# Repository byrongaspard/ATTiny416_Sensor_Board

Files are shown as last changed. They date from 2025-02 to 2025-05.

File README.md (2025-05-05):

# ATTiny416 Dev Board

This project is my first attempt at embedded hardware/software design where I layout/route a custom PCB. In my professional career, I have done schematic capture, integrated Arduino and Raspberry Pi like development boards into custom solutions, and developed embedded software, but this will be my first time laying out a custom circuit card.

There were no real requirements for this design as the primary objective was to learn how to layout a PCB using KiCad. However, to make the design process a little more interesting, I decided I wanted the board to have the following features:

- USB to UART communication to/from the microcontroller
- 3.3V microcontroller (instead of 5V)
- Includes SPI flash for recording data
- Accepts/regulates power from multiple inputs:
  - 5 V from USB
  - 30V from an external power source

The following image is the of the final board. The sections that follow will describe the more interesting portions of the design.

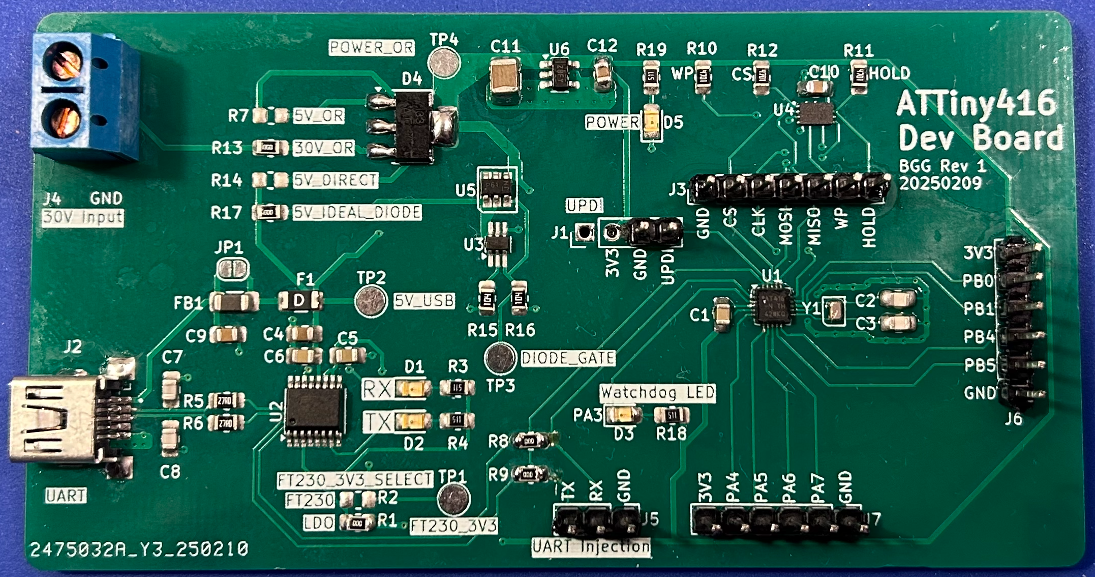
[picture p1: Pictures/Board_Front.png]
Board Front


## Relevant Repository Links

- [KiCad Schematics](KiCad/): Contains the KiCad schematics for the electrical design
  - [Schematic Plots](KiCad/Plots/): Contains the PDF schematics plots for the electrical design
- [SPICE files](SPICE): Contains the LTSpice models used in the design
- [Code](Code): Contains the test code developed for the design

## Hardware Design

The first step in this hardware design was selecting a microcontroller. The ATTiny416 was chosen because of its interesting form factor. It comes in a very small (3x3mm) VQFN package while still providing a lot of the common/core Atmel peripherals found on larger microcontrollers. The USART and SPI peripheral were used in this project. This microcontroller also supports multiple logic levels, including 3.3V. The ATTiny416 is also very easy to integrate into a design as it requires almost no supporting external hardware.

A [ATTiny416 XPLAINED NANO](https://www.microchip.com/en-us/development-tool/attiny416-xnano) development board was purchased to support initial software development while waiting for the PCB to be manufactured/delivered.

### Power

The power design needed to provide the following features:

- Accept 5V USB input power
- Accept up to 30V of external input power
- Accept any combination of power inputs being present at the same time
- Preclude the backfeeding of power from input to input
- Provide a minimum of 50mA @ 3.3V whenever at least one input power is present
  - Provide uninterrupted power when power sources are applied and removed, so long as one input power source is present

The TPS7B6933 LDO linear regulator was selected to generate the 3.3V rail as the microcontroller, SPI flash, and USB to USART peripherals are all relatively low power devices and LDOs are among the simplest power supply designs to implement.
The TPS7B6933 can accept up to 40V (45V transient) of input voltage. The LDO is rated to provide 150mA of output current with a 14V input power source, therefore the maximum output current at 30V can be approximated to ~75mA, meeting the 50 mA requirement.

The simplest way to OR multiple power sources while precluding backfeeding of power would be a diode array. This was considered, but determined to not be feasible. The dropout voltage on the TPS7B6933 is 800mV, meaning 4.1V is the minimum input voltage required to maintain the 3.3V output (3.3V + 0.8V = 4.1V). Most diodes will have a forward voltage drop of approximately 0.7V. According to the USB spec, the minimum USB voltage available at peripherals is 4.35V. Therefore, after this 4.35V input USB power went through a diode, the voltage at the input to the LDO would be 3.65V (4.35V - 0.7V = 3.65V), which is below the TPS7B6933's minimum input voltage of 4.1V.

Therefore, an ideal diode circuit was designed to provide a smaller voltage drop when switching in the 5V USB input, while a regular diode was used to switch in the 30V input.
The DZDH0401DW P-Channel ideal diode controller was chosen primarily because of cost. An N-Channel ideal diode controller would have provided an even smaller voltage drop, but the design did not require this.
The DMP6110SVT was selected as the P-Channel FET primarily for it's relatively low R_DS(on) for a P-Channel FET of 130 mOhm. This R_DS(on) corresponds to a maximum voltage drop of 0.0065V across the FET at the maximum required 50mA output current (0.050A / 130mOhm = 0.0065V). This results in a minimum LDO input voltage of ~4.34VDC when only 5V USB power is present, well above the 4.1V minimum required by the TPS7B6933.

The BAT160 was selected as the diode to switch the 30V input. A LTSpice model was created to tune the ideal diode controller's resistors and to verify circuit functionality before manufacturing. The two images that follow are of the SPICE model where both 5V (4.35V) USB and 30V input power are switched while the 3.3V output is measured.

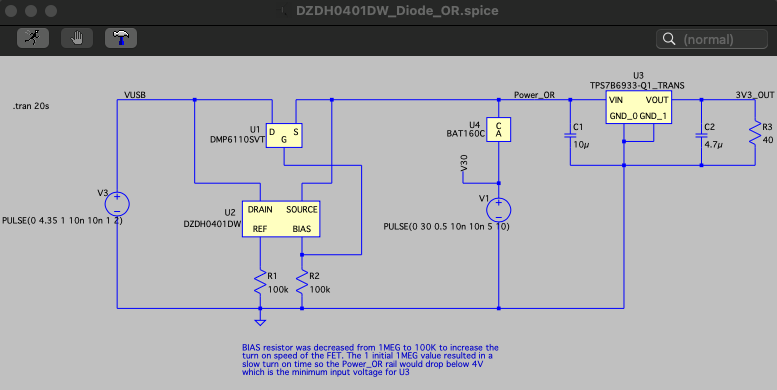
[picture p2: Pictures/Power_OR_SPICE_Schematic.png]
LTSpice Schematic


The colors in the time-base results that follow correspond to the following measurement points:

- Green: 30V input power
- Red: 5V (4.35V) USB input power
- Blue: ORed power from the BAT160 and DZDH0401DW ideal diode circuit
- Pink: 3.3V output power

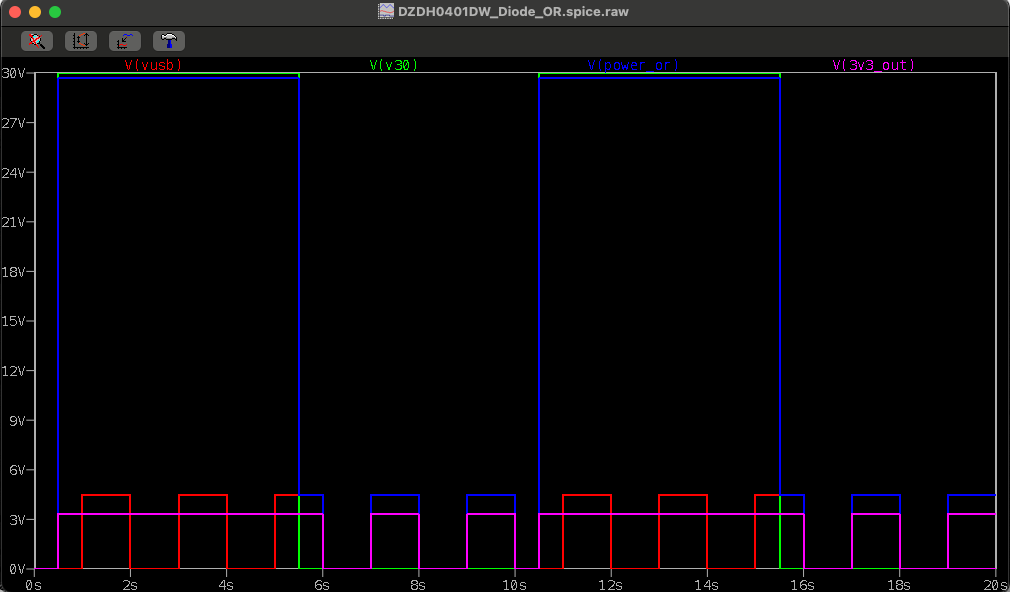
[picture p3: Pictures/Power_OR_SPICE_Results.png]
LTSpice Results


Jumper resistors were also included in the design to allow the diode circuits to be reconfigured or bypassed entirely.

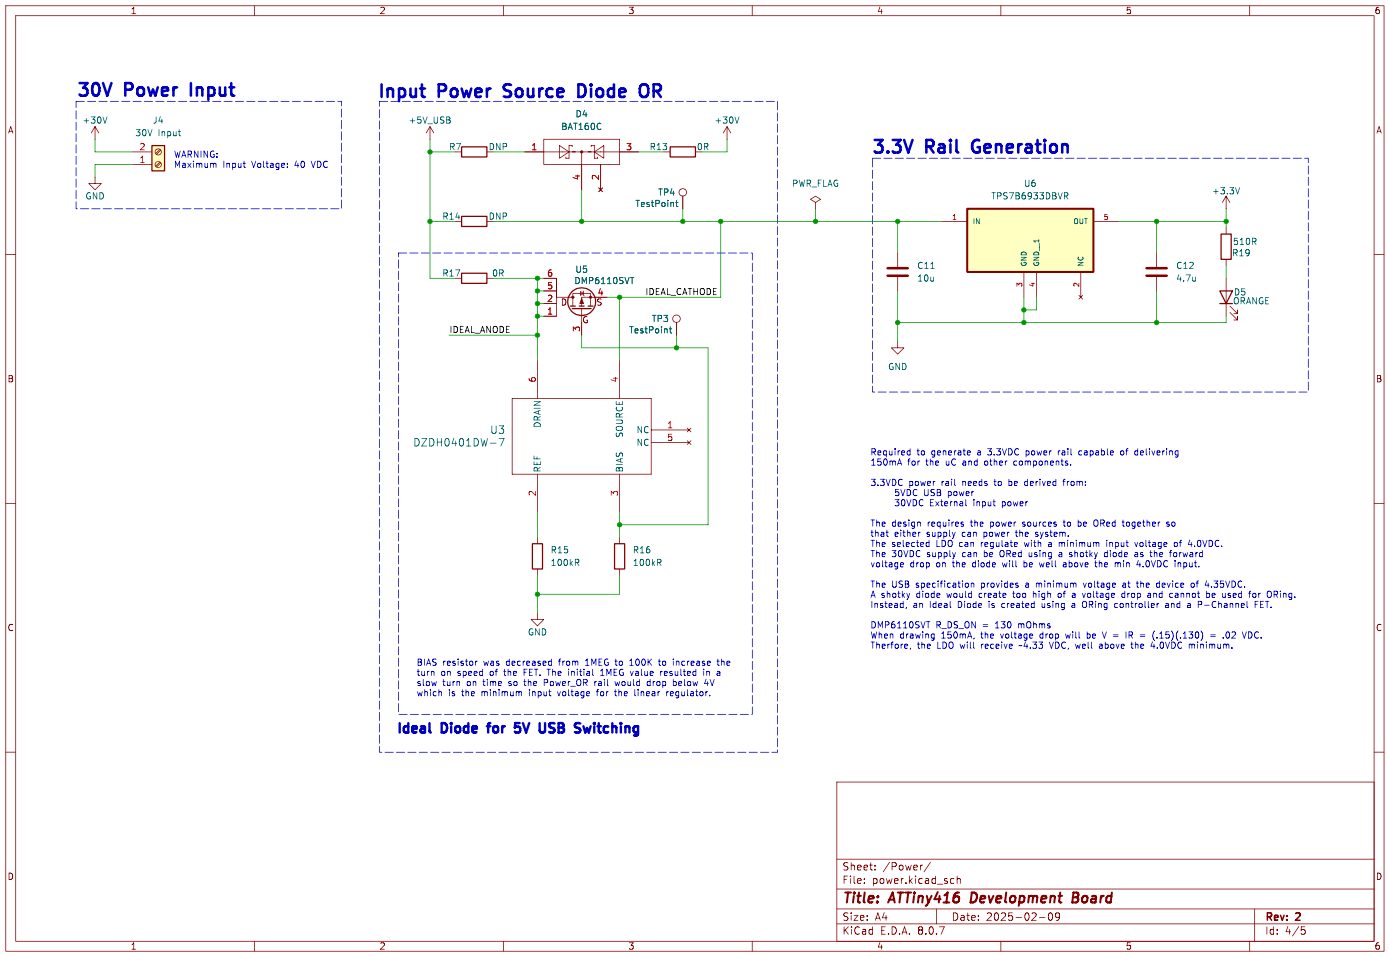
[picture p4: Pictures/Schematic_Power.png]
Power Schematic


### USB to UART

The FT230 was selected to provide the USB to UART interface. This FTDI chip was chosen primarily for it's price. The FT230 datasheet recommended input USB data line filtering capacitors and termination resistors which were added to the design. LEDs were also added to CBUS1/2 on the FT230 to serve as Tx/Rx indicators.

The FT230 uses 5V logic levels on the USB inputs to comply with USB standards, but the UART output logic levels are configurable from 1.8-3.3V via the VCCIO input. The FT230 includes an internal 3.3V LDO on the 3V3OUT pin that can be connected directly to the VCCIO pin to provide the required 3.3V output logic levels. However, it is possible that the FT230's 3.3V regulator is outputting a higher voltage that the circuit card's main TPS7B6933 LDO. Therefore, the output of the design's main 3.3V LDO (TPS7B6933) was connected to the FT230's VCCIO input, instead of connecting the FT230's 3V3OUT.

Jumper resistors were included between the ATTiny416 and FT230 to support isolating the components if needed for debugging. Jumper resistors were also added to allow the FT230's 3V3OUT to be connected to VCCIO instead of the TPS7B6933's 3.3V output if needed.

The 5V USB power that is accepted on the mini-B USB input is also fused here before being utilized/regulated by the TPS7B6933.

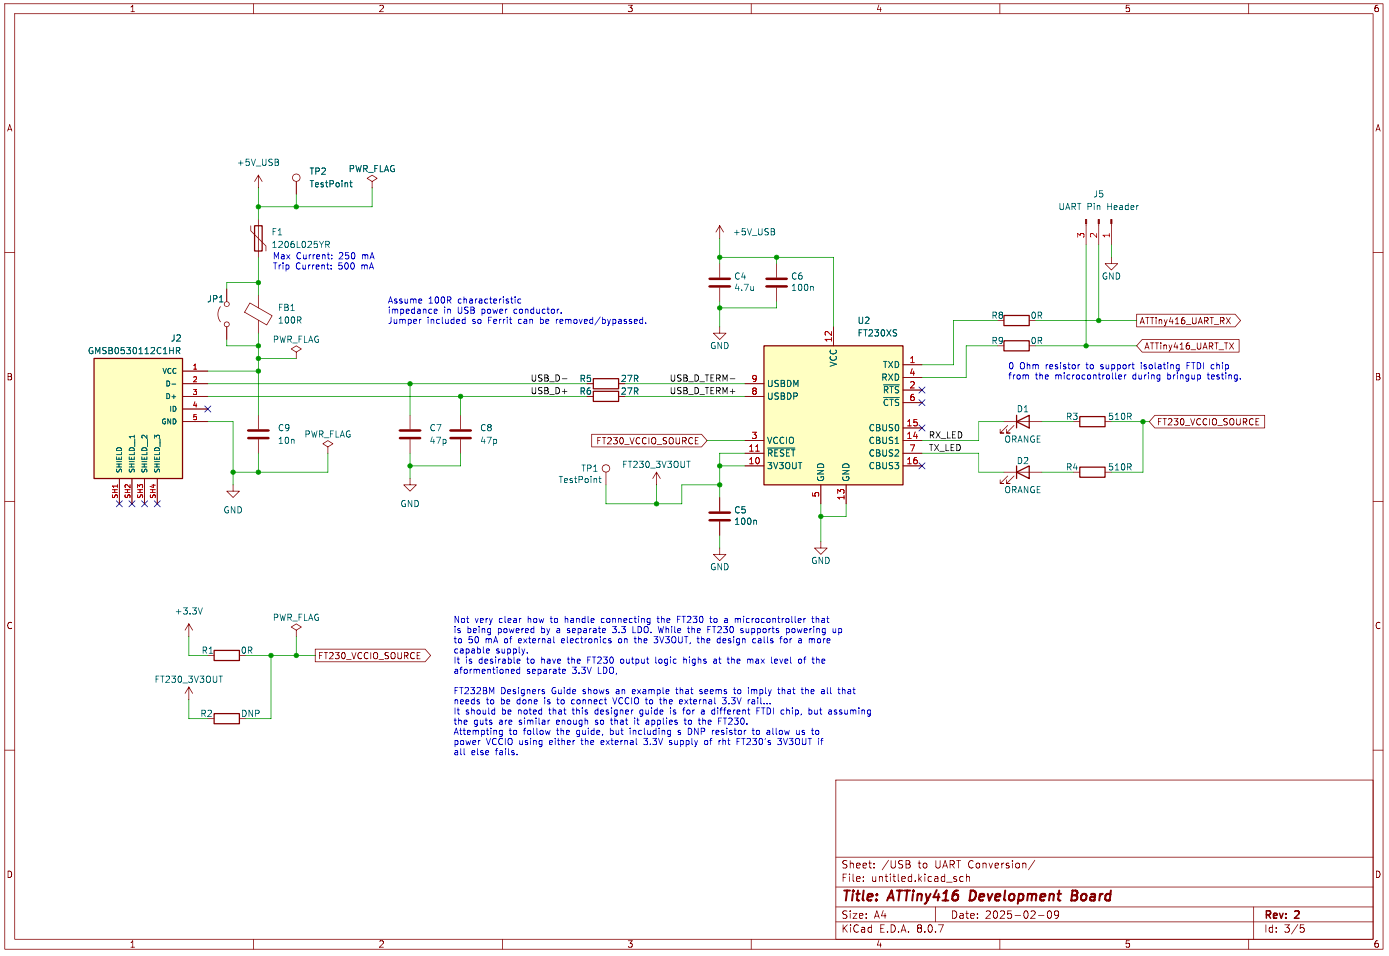
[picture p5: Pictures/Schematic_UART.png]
Power Schematic


### SPI Flash

The W25X20L SPI Flash chip was selected because it supported 3.3V logic levels. Otherwise, any generic SPI Flash chip would have been acceptable. The inverted logic write-protect, hold, and chip select signals were pulled up using external resistors. A debug header was added to all the SPI signal lines to support debugging with logic analyzers if needed. A 4.7uF decoupling capacitor was added to the W25X20L's input power line to provide more stable power, even though the datasheet did not explicitly it.

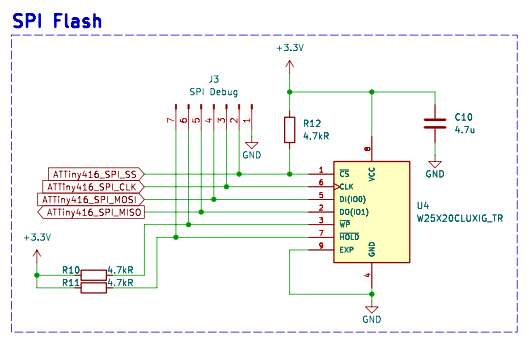
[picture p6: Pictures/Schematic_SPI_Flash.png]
Power Schematic


### PCB Design, Layout, and Manufacture

A two layer board was designed, The top layer contained signals/power and the bottom later was a ground plane. All components were manually placed and all traces were manually routed. The USB data lines were routed as differential pairs. The 32kHz oscillator was surrounded by a guard trace as recommended by the ATTiny416 datasheet. Copper pours were used in the power supply design as was recommended by the manufacturer.

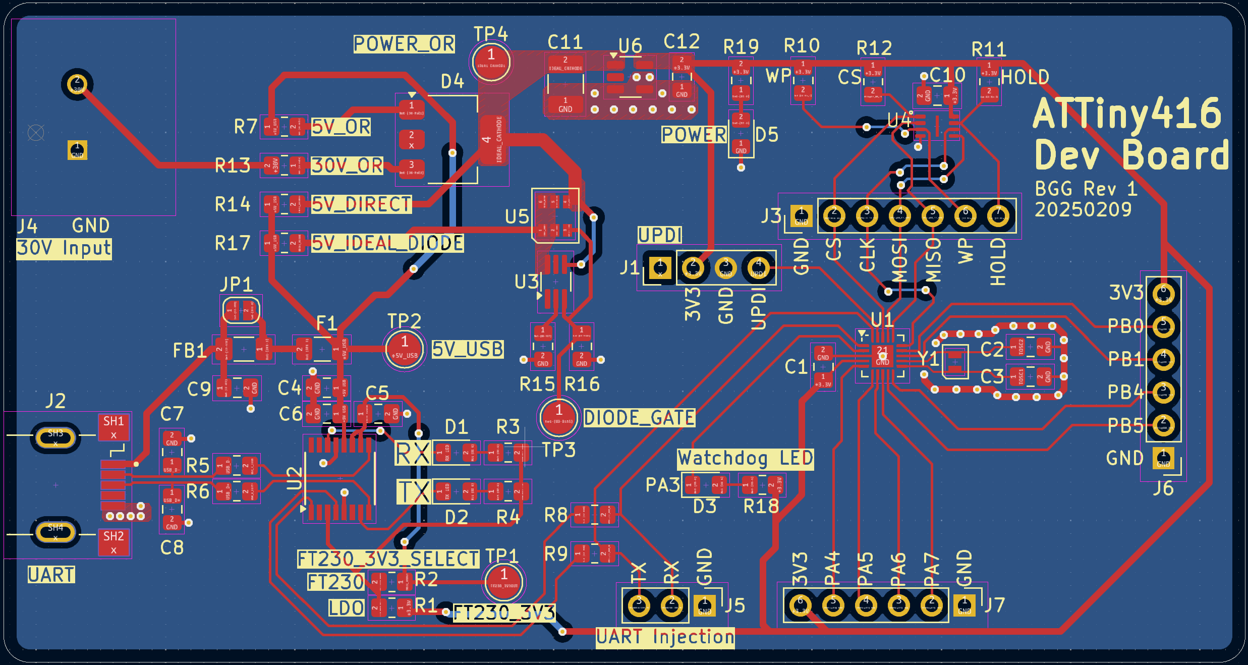
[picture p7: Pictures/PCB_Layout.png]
PCB Layout


The several copies of the PCB were ordered along with a solder paste stencil, as I would be manually assembling this board to support bring-up testing.

## Bring-up Testing

The circuit card was assembled and brought up in the following stages:

1. Power
2. UART
3. Microcontroller
4. SPI Flash

The hardware design was functional and did not require rework.

### Programming

There are multiple 3rd part, DIY, and OEM programmers for the ATTiny416 and other Atmel microcontrollers that use the UPDI interface. The [ICD 5](http://microchip.com/en-us/development-tool/dv164055) from Microchip is the latest OEM programmer and debugger, but it is quite expensive at ~$400. Instead, the [ATTiny416 XPLAINED NANO](https://www.microchip.com/en-us/development-tool/attiny416-xnano) development board was modified to act as a programmer. The dev board was modified by removing R200, which connects the dev board's ATmega32U4 programmer to the dev board's ATTiny416.

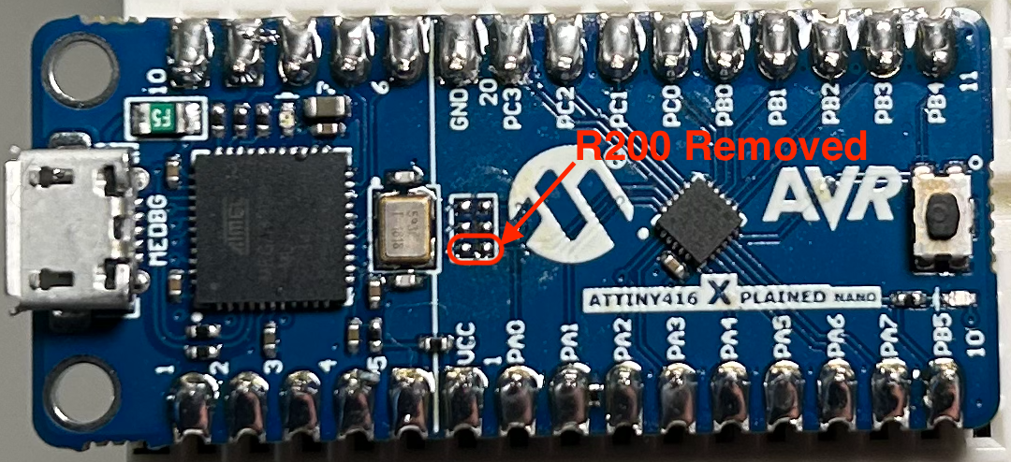
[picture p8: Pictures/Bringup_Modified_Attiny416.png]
Modified ATTiny416 Programmer


Finally, the GND and the ATmega32U4 programmer UPDI output pin could be connected to the programming header on the custom circuit card as shown in the figure below:

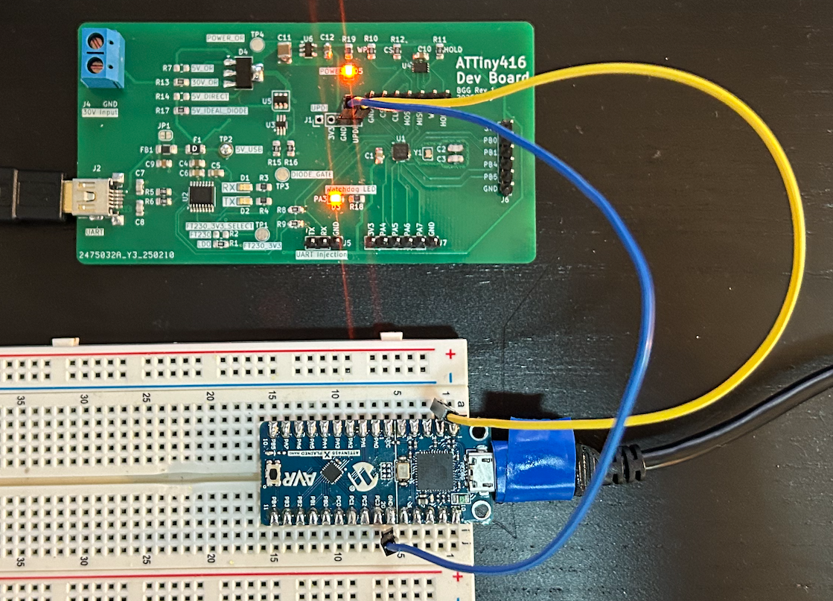
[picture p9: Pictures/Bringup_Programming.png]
Programming Setup


When the ATTiny416 is running on 3.3V input power, none of it's GPIO pins are 5V tolerant, except the reset/programming pin. The reset/programming pin (PA0) can accept up to 12.5V to support the chip's high-voltage reset functionality when PA0 is configured by software as GPIO. This 12.5V tolerance allows 5V logic levels to be used when programming this 3.3V microcontroller without damage.

## Software Design

The objective of the software design was to verify the functionality of all hardware design. To accomplish this, test software was written that provides the following functionality:

- Write a known pattern of data to SPI Flash
- Provide an external command to export the contents of SPI Flash
- Provide an external command to erase the SPI Flash

The code was developed in the MPLAB X IDE and can be found [here](Code), but the diagram that follows describes the high-level code execution flow.

```mermaid
flowchart LR
    Z["Wait forever until reset (Infinite Loop)."]
    A[Start] --> B[Initialize uC GPIO and peripherals]
    B --> C{Dump Flash Command Asserted?}
    C --> |YES| D[Dump Flash over UART.]
    D --> Z
    C --> |NO| E{Erase Flash Command Asserted?}
    E --> |YES| F[Erase Flash and notify when erase is complete over UART.]
    F --> Z
    E --> |NO| G{Is storage remaining in Flash?}
    G --> |YES| H[Write data pattern to Flash.]
    H --> G
    G --> |NO| Z
```

The external commands to export and erase SPI Flash were implemented using two ATTiny416 GPIO interfaces:

- PA6 = ERASE_N
- PA7 = DUMP_N

The ATTiny416's internal pull-up resistors were enabled for the dump and erase pin (PA6 & PA7). The software then uses inverted logic at initialization when interpreting these pins to decide when to erase and dump Flash.

To erase Flash, an operator would:

1. Connect PA6 to GND
2. Reset the ATTiny416
3. UART interface can be monitored for software indication of erase completion.

Similarly, to dump Flash, an operator would:

1. Connect PA7 to GND
2. Reset the ATTiny416
3. Receive the contents of Flash over the UART interface.

The dump Flash command is given priority over the erase Flash command, so if both are ever asserted at the same time, the ATTiny416 will dump the contents of Flash instead of erasing.

These command interfaces are only interrogated by software during initialization. If neither are asserted when the microcontroller is released from reset, the normal Flash recording loop will be entered. Inverted logic is used for these interfaces to protect the ATTiny416 from expected behavior caused by applying voltage to GPIO pins while no power is applied to the microcontroller itself.

The FT230 to ATTiny416 serial receive functionality was verified in bring-up test code that was not included in this repository.

### Software Testing Results

The screen captures that follow are of the ATTiny416's UART outputs while testing software.

The following screenshot shows three separate boot events, each starting with the "Booting..." text. When the software initializes, it determines that neither of the erase or dump flash inputs are asserted, and proceeds to enter the recording loop. To find where the software can begin writing to without overwriting previously recorded data, the software iterates through all of flash until it finds uninitialized memory (0xFF).

The first boot shown occurred right after SPI flash was erased, as the start of memory was detected at the 0x0000 address. The second boot shown occurred after some of flash has been written to, as the start of memory is reported as 0x001010, instead of 0x000000. The program was then allowed to run until flash was completely full, which was when the "Aborting W25X20L write... not enough memory left" message was printed. The third and final boot shown occurred after SPI flash was completely full, which is why the software was unable to find uninitialized flash and the "Could not find start of memory" message was printed.

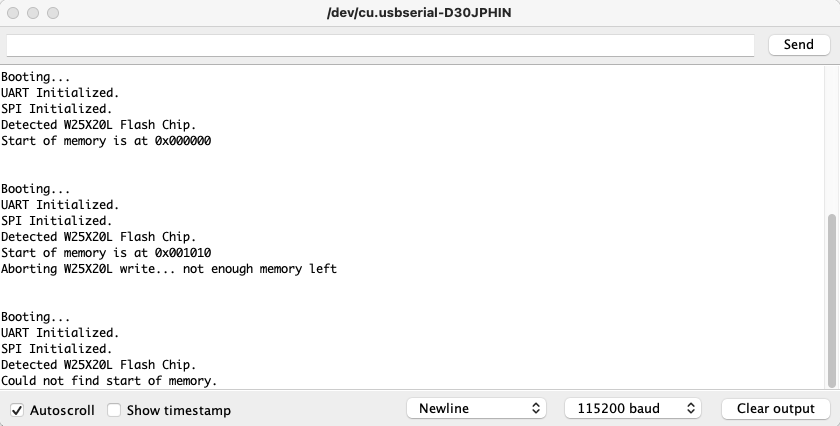
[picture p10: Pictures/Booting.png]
Booting


The next two images show the UART output when the dump flash command was asserted at reset. The entire contents of the W25X20L flash area printed to the console in HEX, followed by a two's-compliment checksum.

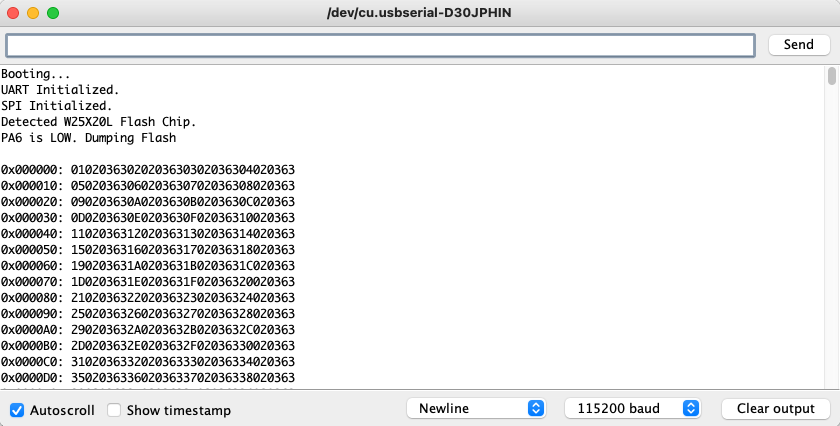
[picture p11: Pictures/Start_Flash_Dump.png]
Start Flash Dump


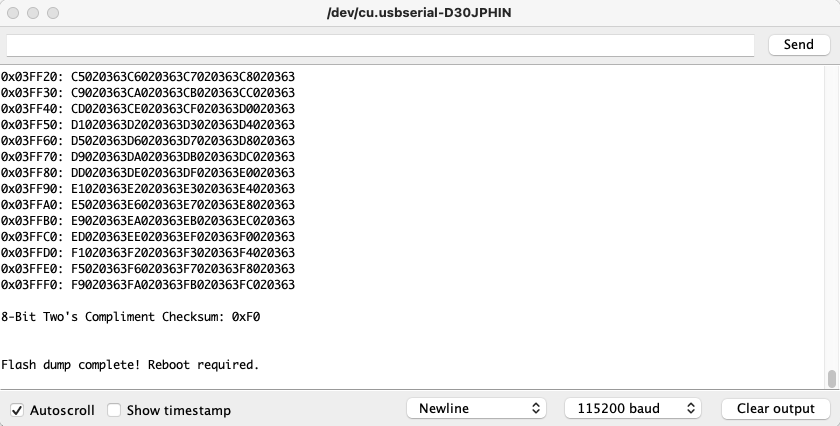
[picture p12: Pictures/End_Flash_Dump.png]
End Flash Dump


The final image below shows the UART output when the erase flash command was asserted at reset. The software reports when the W25X20L chip has completed erasing.

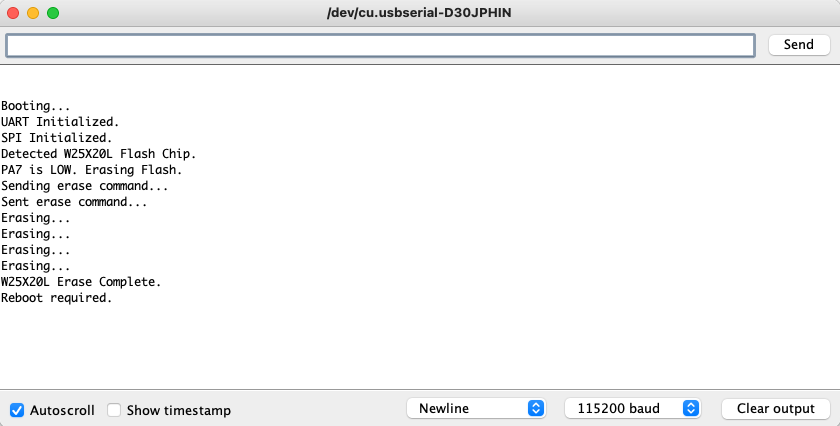
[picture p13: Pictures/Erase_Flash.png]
Erasing


# Summary

This project was a lot of fun and gave me a lot more confidence with the PCB layout portions of hardware design. The layout requirements for this design were very simple as we didn't have to contend with high-power, high-speed signals, noise, etc., but it was still a fun and rewarding learning experience for me.

## Additional Work

The following can still be completed on this project:

- Test the external 32kHz crystal oscillator

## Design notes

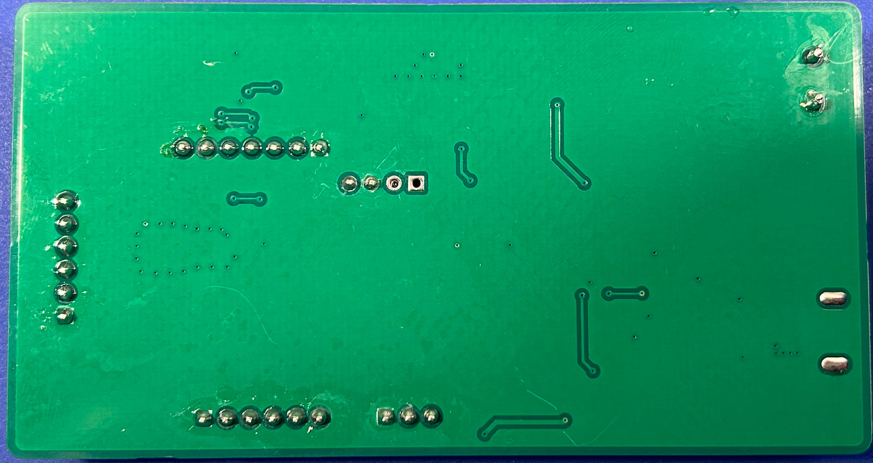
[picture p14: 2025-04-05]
Pictures/Board_Back.png

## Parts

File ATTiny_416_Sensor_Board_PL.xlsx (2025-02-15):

Reference | Value | Datasheet | Footprint | Qty | DNP | PN
C1,C5,C6 | 100n | ~ | Capacitor_SMD:C_0805_2012Metric_Pad1.18x1.45mm_HandSolder | 3
C2,C3 | 8.5p | ~ | Capacitor_SMD:C_0805_2012Metric_Pad1.18x1.45mm_HandSolder | 2
C4,C10,C12 | 4.7u | ~ | Capacitor_SMD:C_0805_2012Metric_Pad1.18x1.45mm_HandSolder | 3
C7,C8 | 47p | ~ | Capacitor_SMD:C_0805_2012Metric_Pad1.18x1.45mm_HandSolder | 2
C9 | 10n | ~ | Capacitor_SMD:C_0805_2012Metric_Pad1.18x1.45mm_HandSolder | 1
C11 | 10u | ~ | Capacitor_SMD:C_1210_3225Metric_Pad1.33x2.70mm_HandSolder | 1
D1,D2,D3 | ORANGE | ~ | Diode_SMD:D_0805_2012Metric_Pad1.15x1.40mm_HandSolder | 3 |  | SML-211DTT86
D4 | BAT160C |  | Package_TO_SOT_SMD:SOT-223 | 1 |  | BAT160C
F1 | 1206L025YR | ~ | Fuse:Fuse_1206_3216Metric | 1 |  | 1206L025YR
FB1 | 100R | ~ | Resistor_SMD:R_1206_3216Metric_Pad1.30x1.75mm_HandSolder | 1 |  | HI1206N101R-10
J1 | UPDI Header | ~ | Connector_PinHeader_2.54mm:PinHeader_1x04_P2.54mm_Vertical | 1
J2 | GMSB0530112C1HR |  | GMSB0530112C1HR:AMPHENOL_GMSB0530112C1HR | 1 |  | GMSB0530112C1HR
J3 | SPI Debug | ~ | Connector_PinHeader_2.54mm:PinHeader_1x07_P2.54mm_Vertical | 1
J4 | 30V Input | ~ | Two_Position_Screw_Terinal:Two_Position_Screw_Terminal | 1
J5 | UART Pin Header | ~ | Connector_PinHeader_2.54mm:PinHeader_1x03_P2.54mm_Vertical | 1
J6 | GPIO2 | ~ | Connector_PinHeader_2.54mm:PinHeader_1x06_P2.54mm_Vertical | 1
J7 | GPIO1 | ~ | Connector_PinHeader_2.54mm:PinHeader_1x06_P2.54mm_Vertical | 1
JP1 | ~ | ~ | Jumper:SolderJumper-2_P1.3mm_Open_RoundedPad1.0x1.5mm | 1
R1,R8,R9,R13,R17 | 0R | ~ | Resistor_SMD:R_0805_2012Metric_Pad1.20x1.40mm_HandSolder | 5 |  | NRC06ZOTRF
R2,R7,R14 | DNP | ~ | Resistor_SMD:R_0805_2012Metric_Pad1.20x1.40mm_HandSolder | 3 |  | NRC06ZOTRF
R3,R4,R18 | 510R | ~ | Resistor_SMD:R_0805_2012Metric_Pad1.20x1.40mm_HandSolder | 3 |  | RC0603FR-0778R7L
R5,R6 | 27R | ~ | Resistor_SMD:R_0805_2012Metric_Pad1.20x1.40mm_HandSolder | 2
R10,R11,R12 | 4.7kR | ~ | Resistor_SMD:R_0805_2012Metric_Pad1.20x1.40mm_HandSolder | 3
R15,R16 | 100kR | ~ | Resistor_SMD:R_0805_2012Metric_Pad1.20x1.40mm_HandSolder | 2
TP1,TP2,TP3,TP4 | TestPoint | ~ | TestPoint:TestPoint_Pad_D2.5mm | 4
U1 | ATtiny416-M | http://ww1.microchip.com/downloads/en/DeviceDoc/40001913A.pdf | Package_DFN_QFN:VQFN-20-1EP_3x3mm_P0.4mm_EP1.7x1.7mm | 1
U2 | FT230XS | https://www.ftdichip.com/Support/Documents/DataSheets/ICs/DS_FT230X.pdf | Package_SO:SSOP-16_3.9x4.9mm_P0.635mm | 1
U3 | DZDH0401DW-7 | DZDH0401DW-7 | Package_TO_SOT_SMD:SOT-363_SC-70-6_Handsoldering | 1 |  | DZDH0401DW-7
U4 | W25X20CLUXIG_TR |  | W25X20CLUXIG TR:W25X20CLUXIG TR | 1 |  | W25X20CLUXIG_TR
U5 | DMP6110SVT |  | DMP6110SVT:DMP6110SVT | 1 |  | DMP6110SVT
U6 | TPS7B6933DBVR |  | Package_TO_SOT_SMD:SOT-23-5 | 1
Y1 | 32.768 kHz | ~ | NX1610SE:NX1610SE | 1 |  | NX1610SE

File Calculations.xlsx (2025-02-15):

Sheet: 32kHz Crystal Load Capacitors
Calculate External Load Capacitor Required for 32 kHz Crystal.
Solved a simplified version of Equation 3-5 for C_P, assuming:
 | C_P = C_P1 = C_P2 = External Load capactor values
 | C_EL = C_EL1 = C_EL2 = External parasitic capacitance
 | C_L = C_L1 = C_L2 = ATTiny416 internal parasitic capacitance.
 | C_T = Total load capacitance (Set with value from selected crystal)
 | Simplified Equation 3-5:
 |  | C_T = ((C_L + C_P + C_EL)^2)/(2C_L + 2C_P + 2C_EL)
 | Simplified Equation 3-5 solved for C_P:
 |  | C_P = 2C_T - C_L - C_EL
C_P Solver
Variable | Value [pF] | Reference
C_T | 9 | MU01499-32.768K Datasheet
C_L | 4.5 | ATTiny416 Datasheet
C_EL | 0 | Assumed
C_P | 13.5 | Calculated
Other Random Junk
Equation 3-5 Solver
Variable | Value [pF] | Reference
C_L1 | 4.5 | Internal Parasitic Load Capacitance from ATTiny416 Datasheet
C_L2 | 4.5 | Internal Parasitic Load Capacitance from ATTiny416 Datasheet
C_EL1 | 8.5 | External Load Capacitor
C_EL2 | 8.5 | External Load Capacitor
C_P1 | 5 | Assumed parasitics in board
C_P2 | 5 | Assumed parasitics in board
C_L | 9

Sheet: SPI Flash Calculations
Sample Bytes | 2
Sample Bits | 16
Sample Rate [Hz] | 1000
Bits/Sec | 16000
Bits/Min | 960000
Run Time [min] | 30
Total Data [Bits] | 28800000
Total Data [Mbit] | 27.38558909

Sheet: LED Calculations
VCC | 3.3
PN | EAST2012RA2
Color | RED
VF_Min | 1.8
VF_Max | 1.8
IF | 0.003
R_MAX | 500
R_P [Watt] | 0.0045 | 1.5 | 0.003

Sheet: POWER
3.3
0.09 | 36.66666667

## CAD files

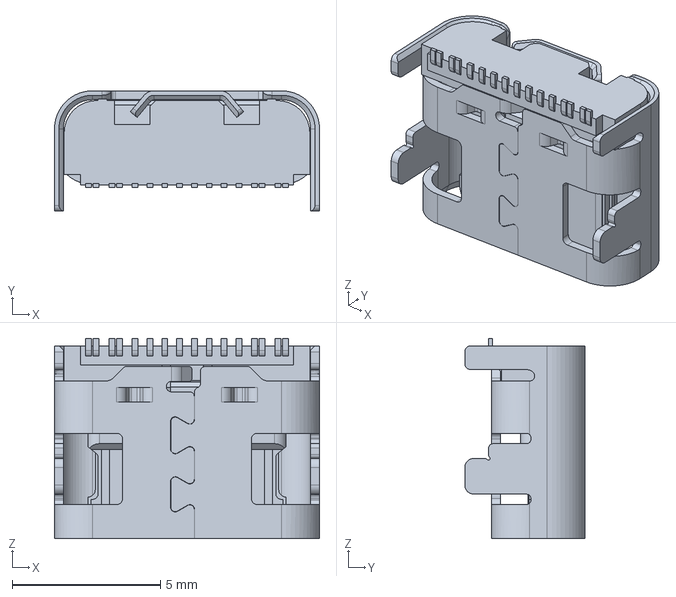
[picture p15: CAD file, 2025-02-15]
Symbols/2171790001/2171790001.stp
8.94 x 4.06 x 6.75 mm

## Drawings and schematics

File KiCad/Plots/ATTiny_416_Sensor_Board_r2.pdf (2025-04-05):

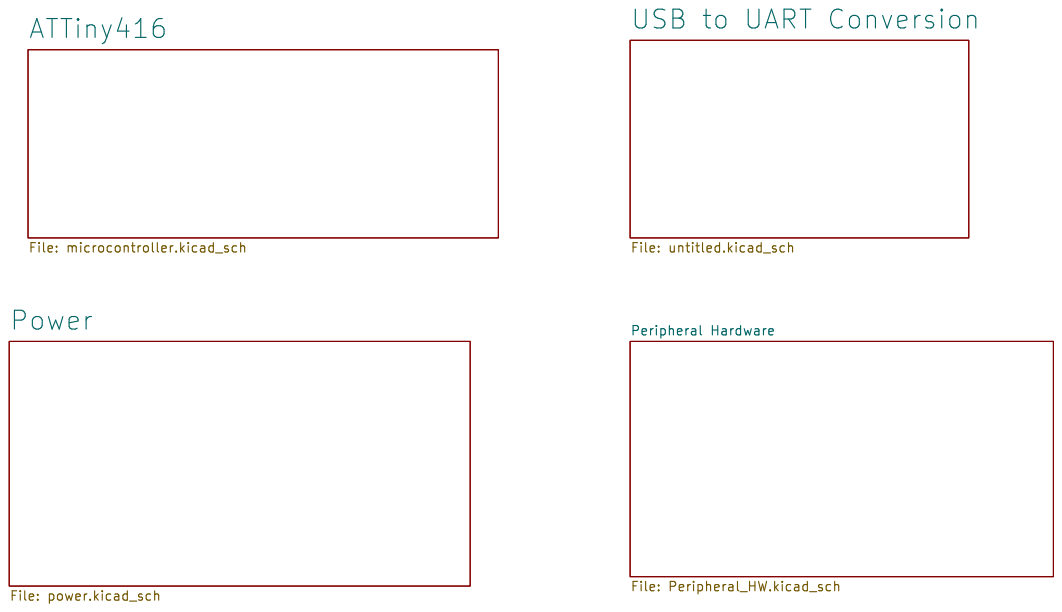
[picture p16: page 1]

USB to UART Conversion

Id: 1/5 Title: ATTiny416 Development Board

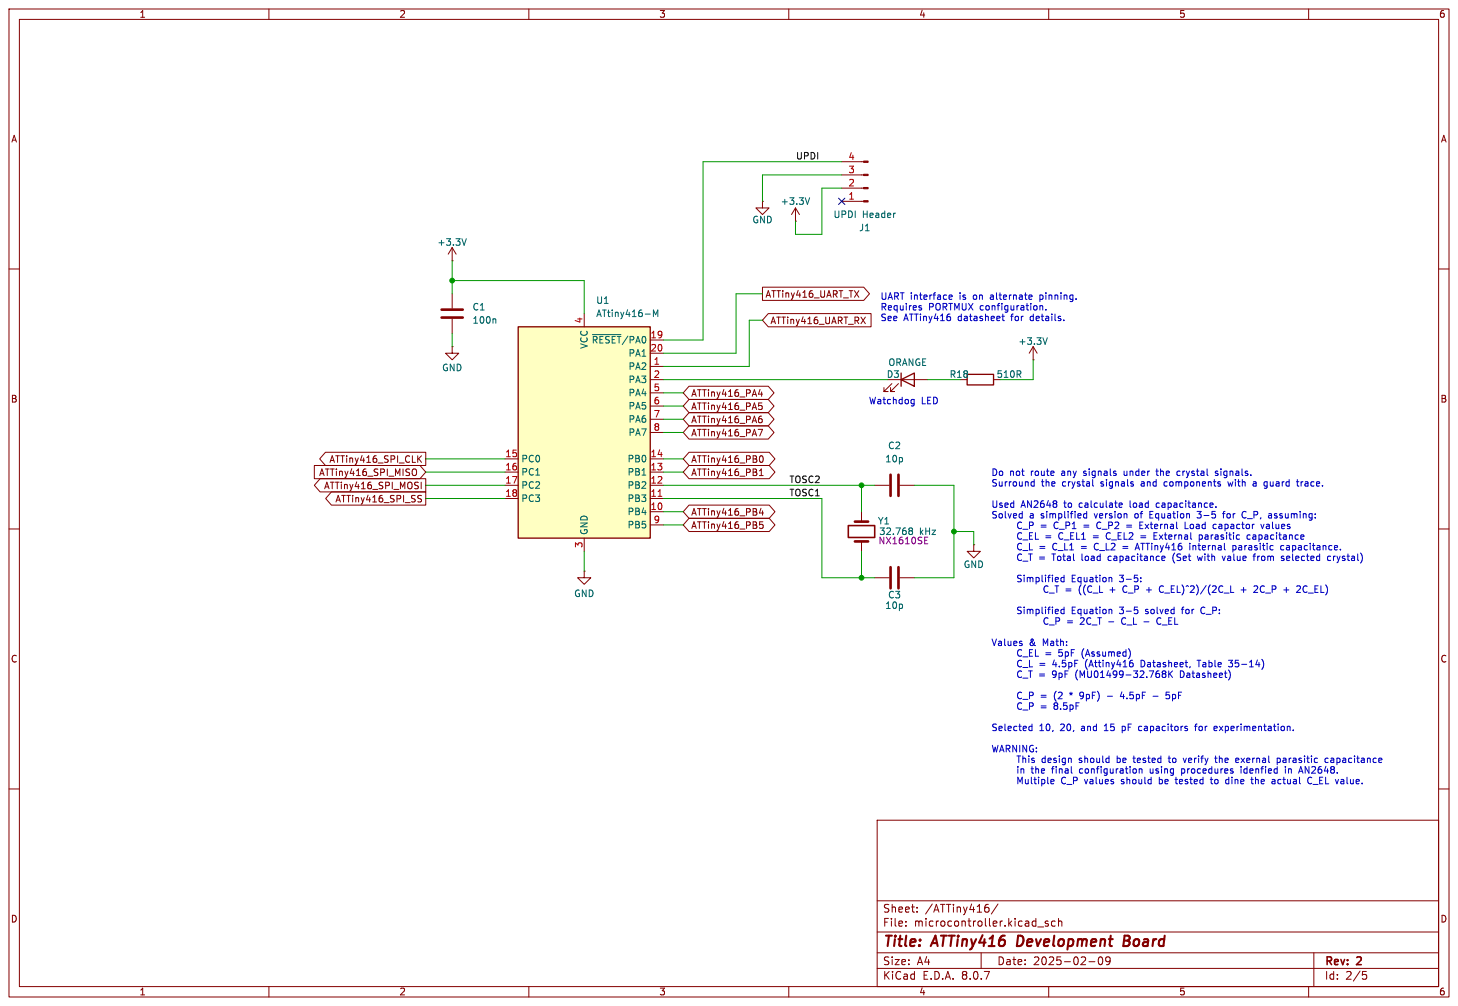
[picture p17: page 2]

File: microcontroller.kicad_sch Sheet: /ATTiny416/
Id: 2/5 Title: ATTiny416 Development Board

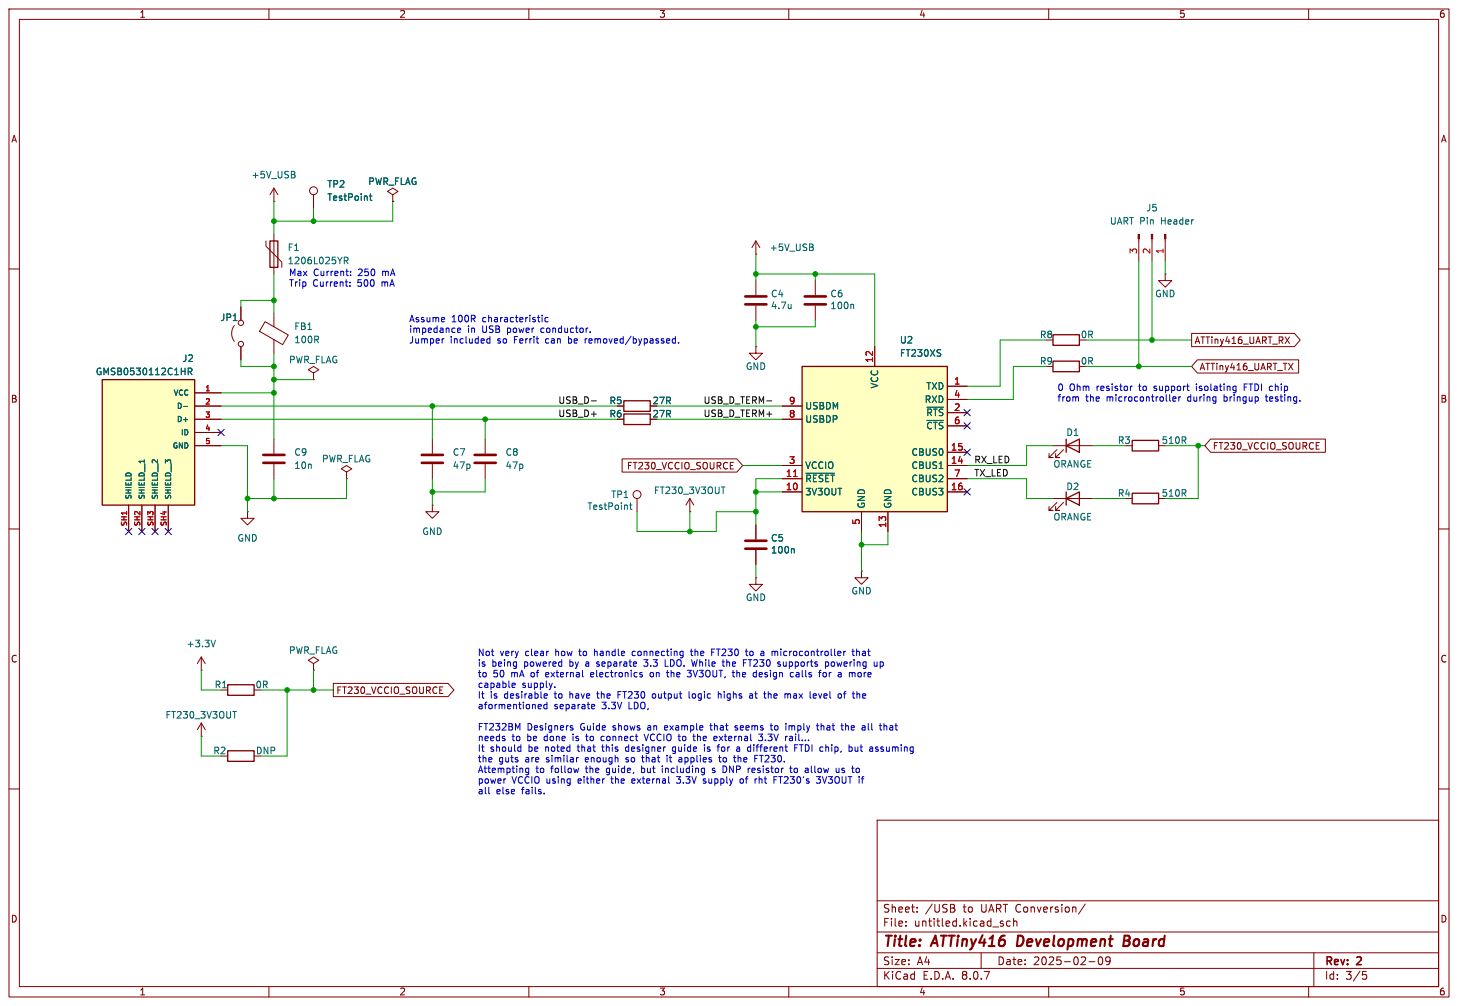
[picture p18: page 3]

J5 UART Pin Header GND

Id: 3/5 Title: ATTiny416 Development Board

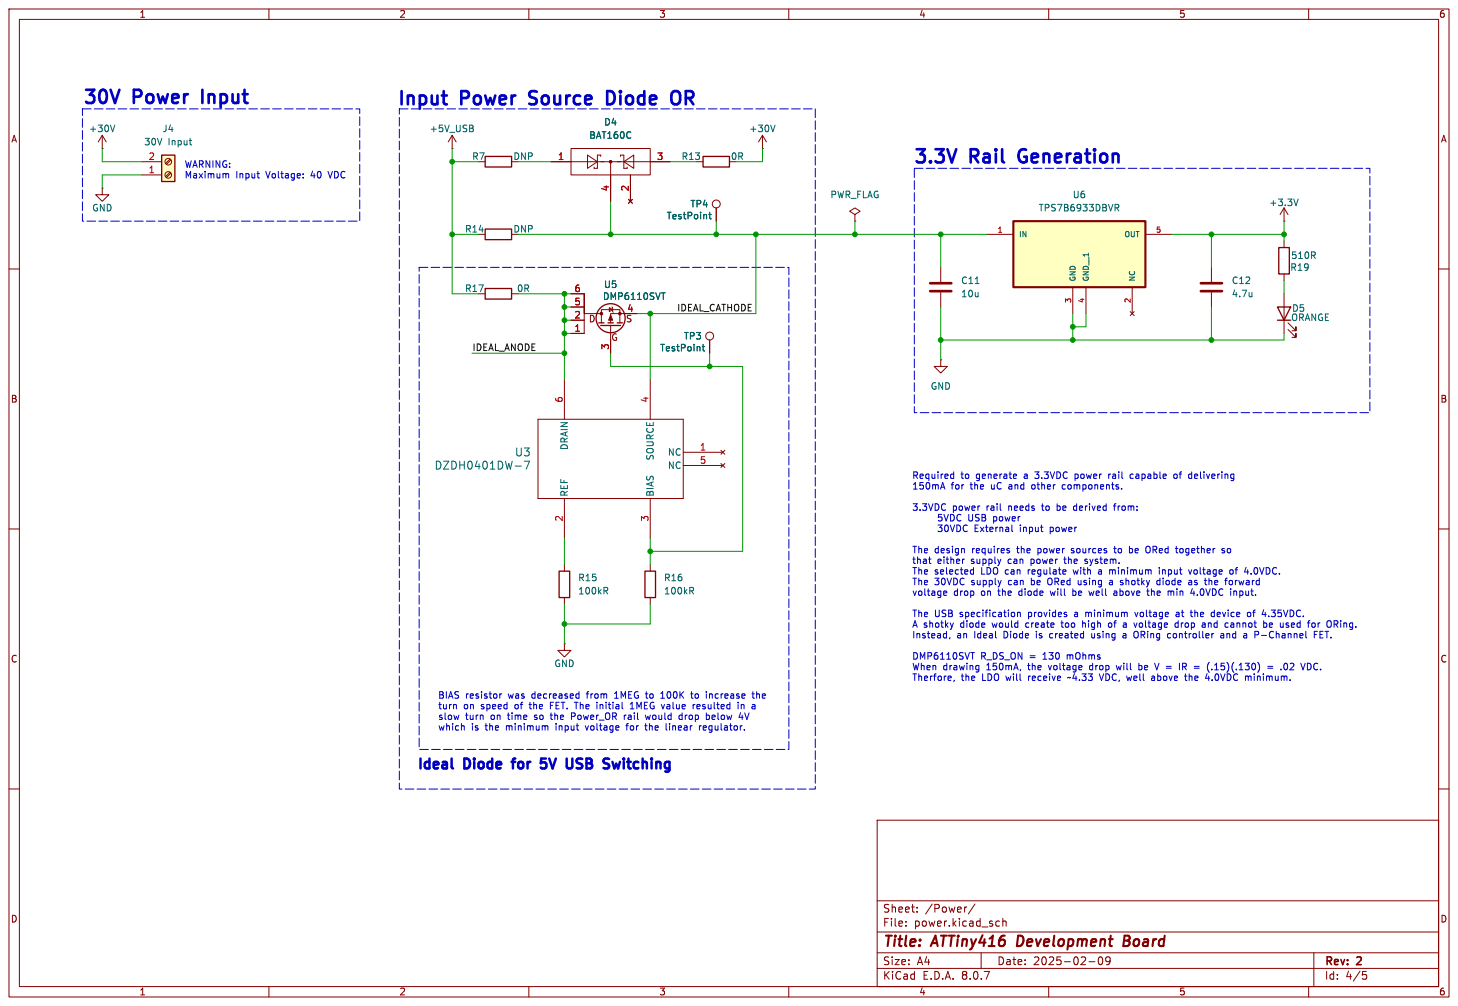
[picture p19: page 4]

WARNING: Maximum Input Voltage: 40 VDC

Required to generate a 3.3VDC power rail capable of delivering

File: power.kicad_sch Sheet: /Power/
Id: 4/5 Title: ATTiny416 Development Board

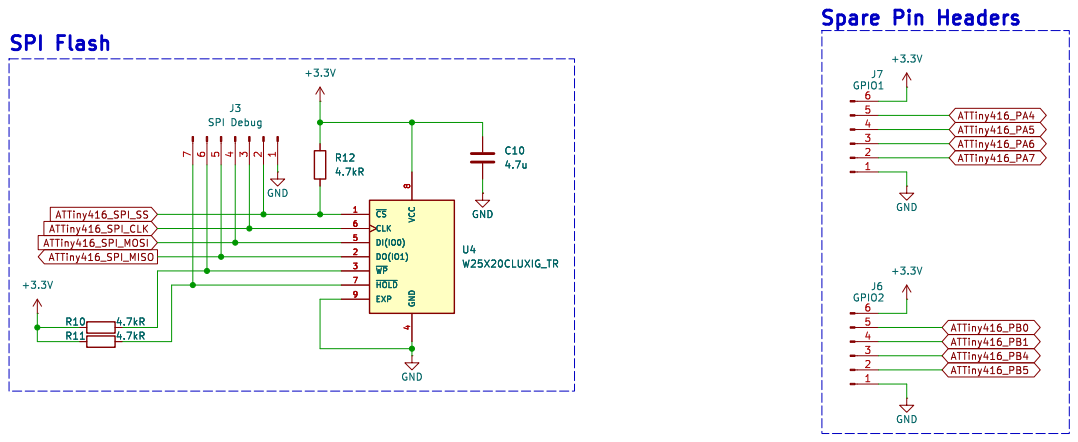
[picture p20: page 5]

4 DI(IO0) 5 CLK 6 ~{HOLD} 7 VCC

Id: 5/5 Title: ATTiny416 Development Board

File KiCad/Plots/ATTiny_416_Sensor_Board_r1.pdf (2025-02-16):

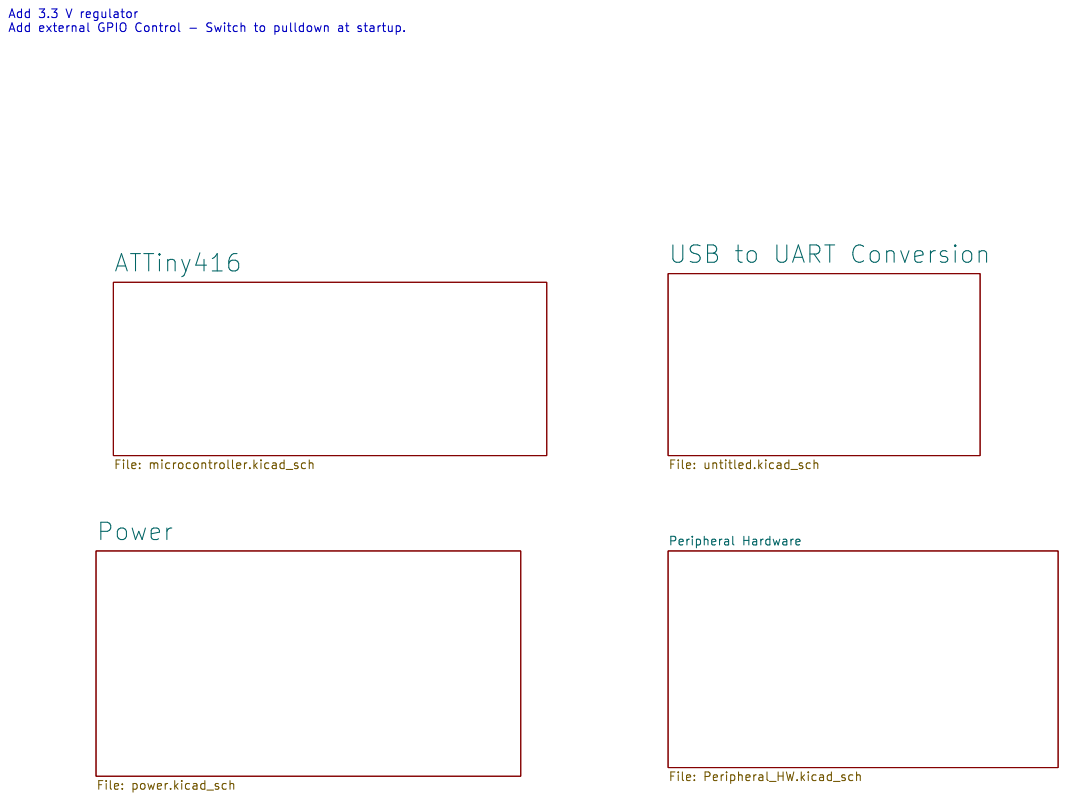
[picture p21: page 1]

USB to UART Conversion

Id: 1/5 Title: ATTiny416 Development Board

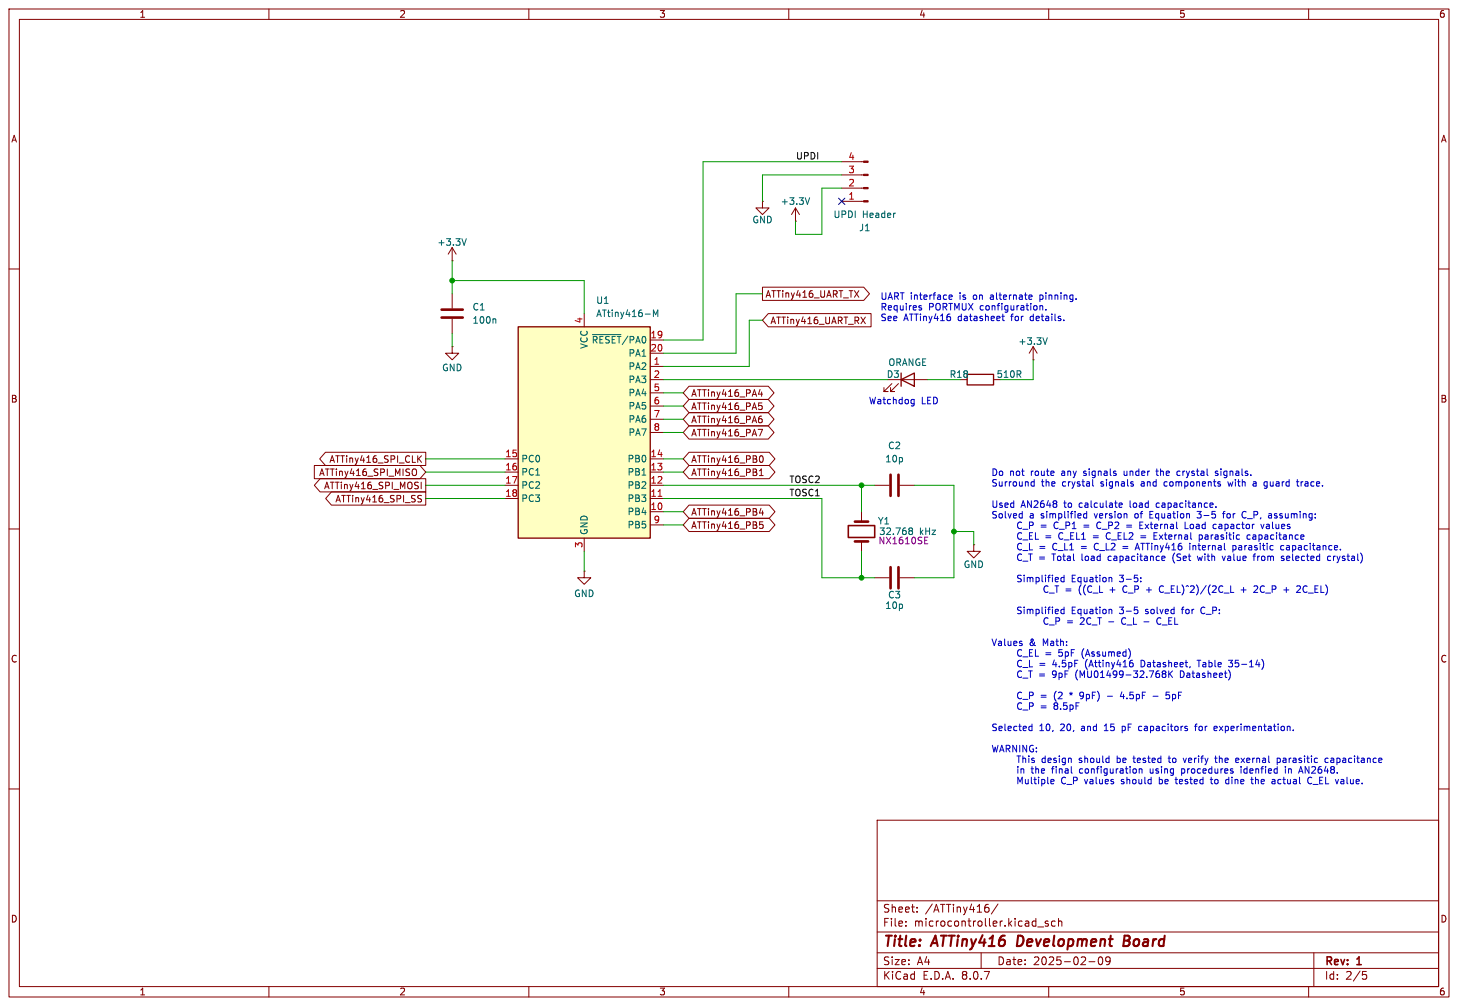
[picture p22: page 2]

File: microcontroller.kicad_sch Sheet: /ATTiny416/
Id: 2/5 Title: ATTiny416 Development Board

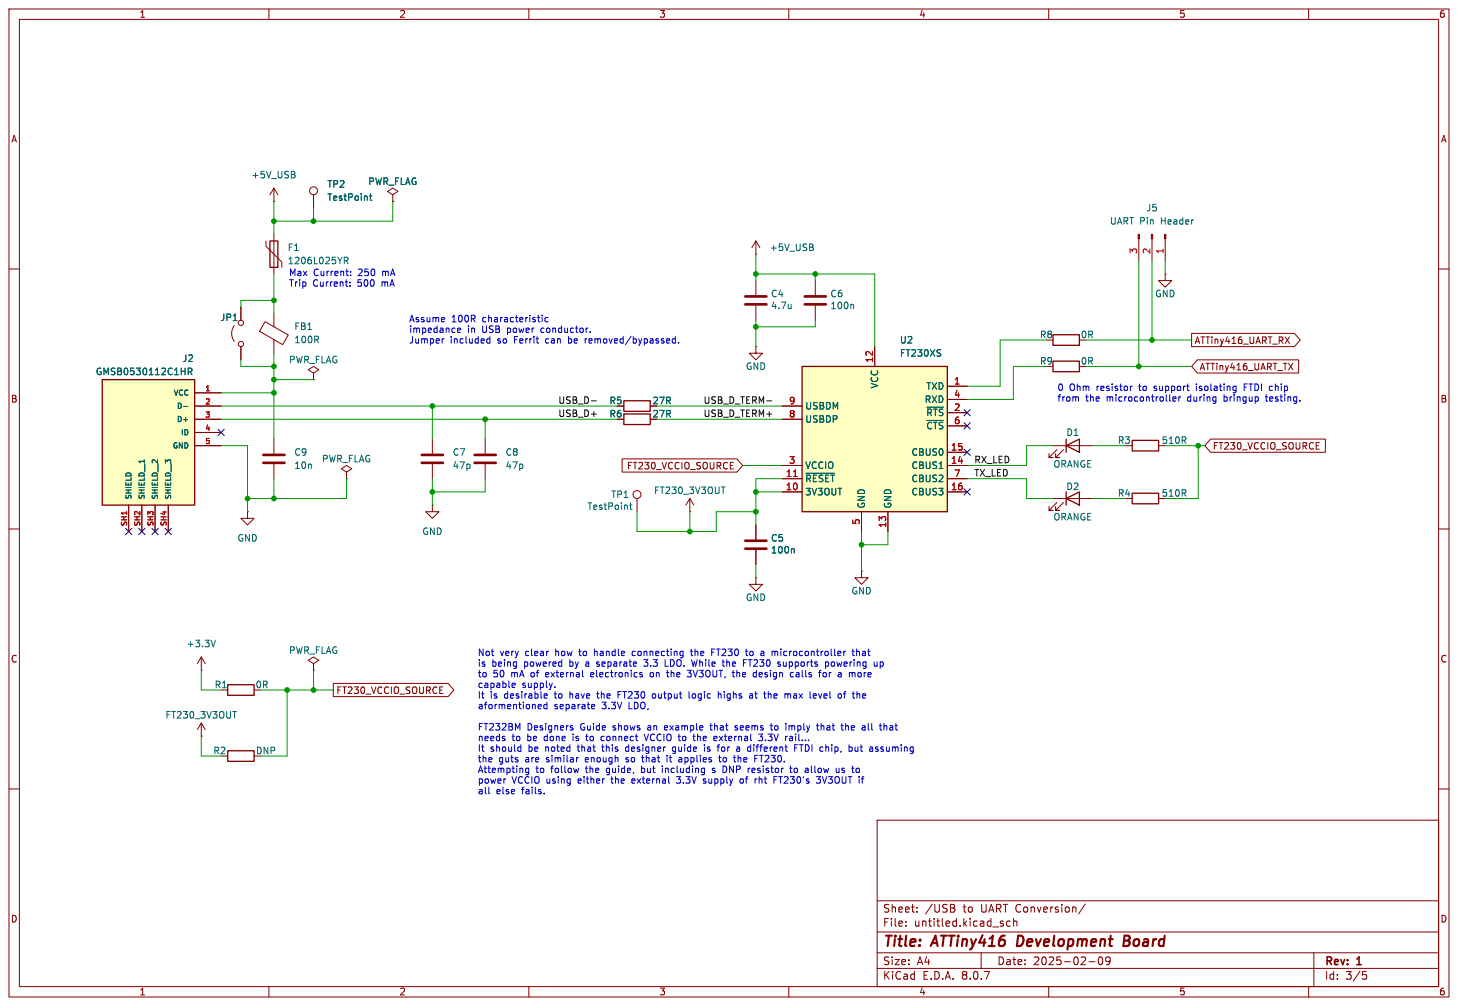
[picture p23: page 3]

J5 UART Pin Header GND

Id: 3/5 Title: ATTiny416 Development Board

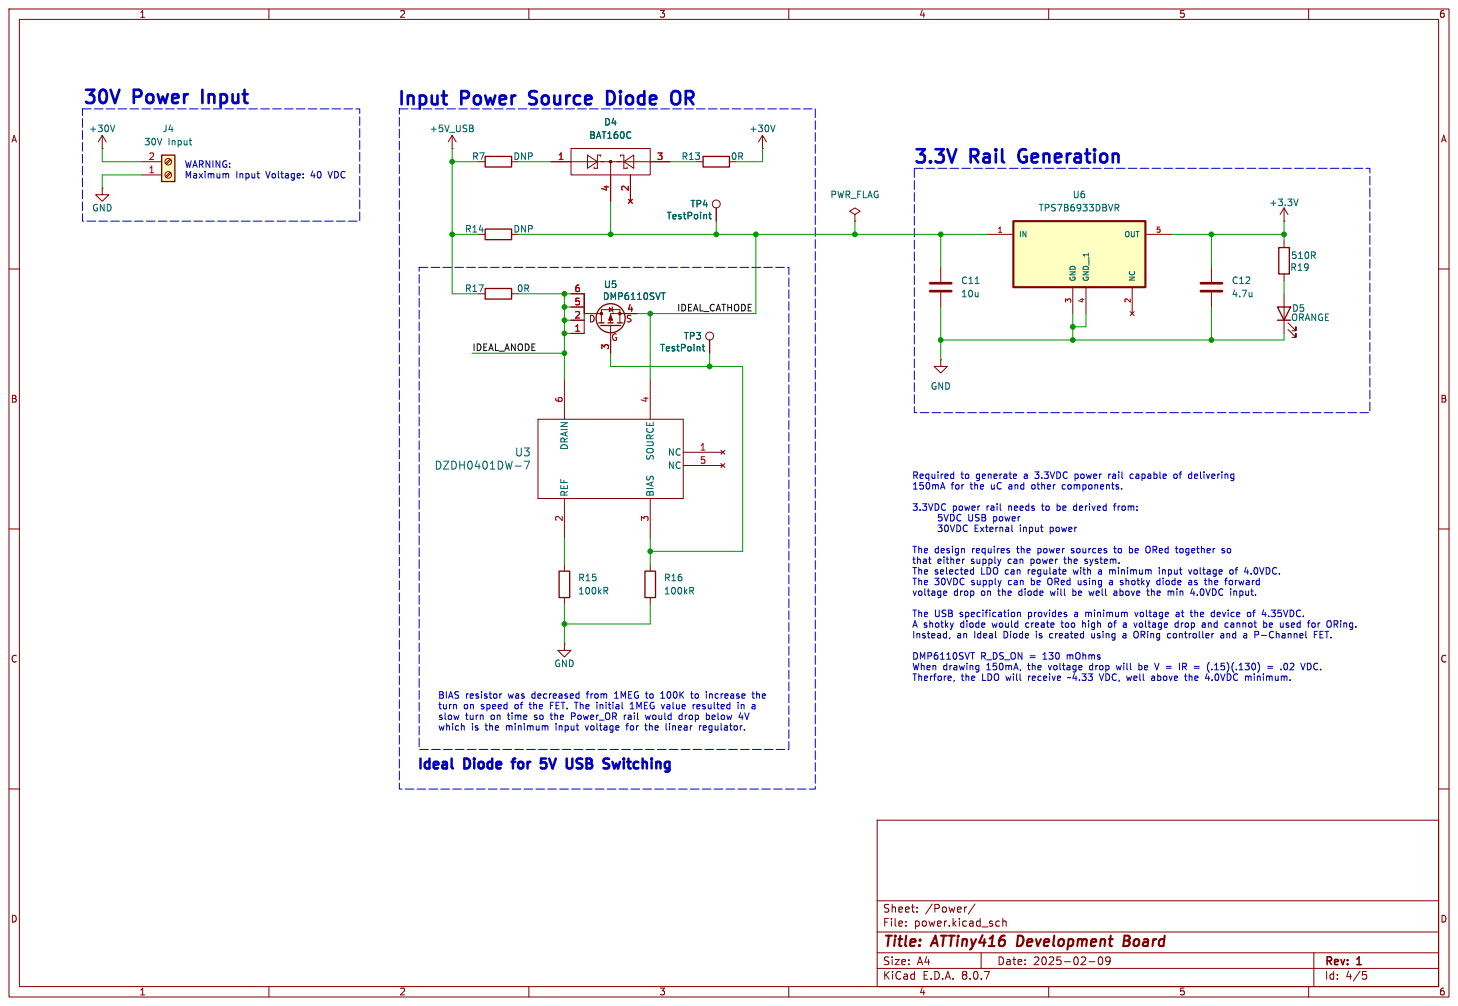
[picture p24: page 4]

WARNING: Maximum Input Voltage: 40 VDC

Required to generate a 3.3VDC power rail capable of delivering

File: power.kicad_sch Sheet: /Power/
Id: 4/5 Title: ATTiny416 Development Board


4 DI(IO0) 5 CLK 6 ~{HOLD} 7 VCC

Id: 5/5 Title: ATTiny416 Development Board

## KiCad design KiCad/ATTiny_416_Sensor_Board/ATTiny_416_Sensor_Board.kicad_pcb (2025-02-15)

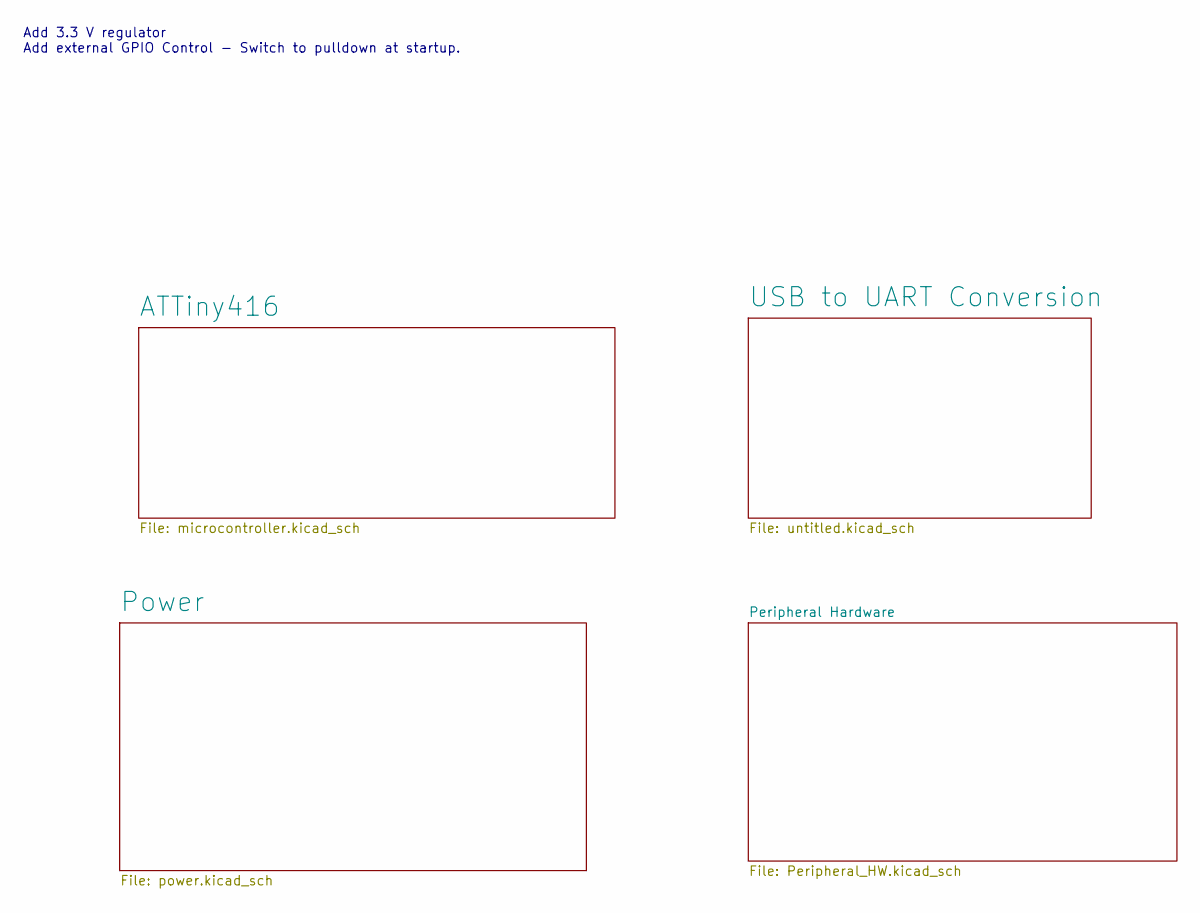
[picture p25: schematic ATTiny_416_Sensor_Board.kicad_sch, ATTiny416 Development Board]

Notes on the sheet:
Add 3.3 V regulator Add external GPIO Control - Switch to pulldown at startup.

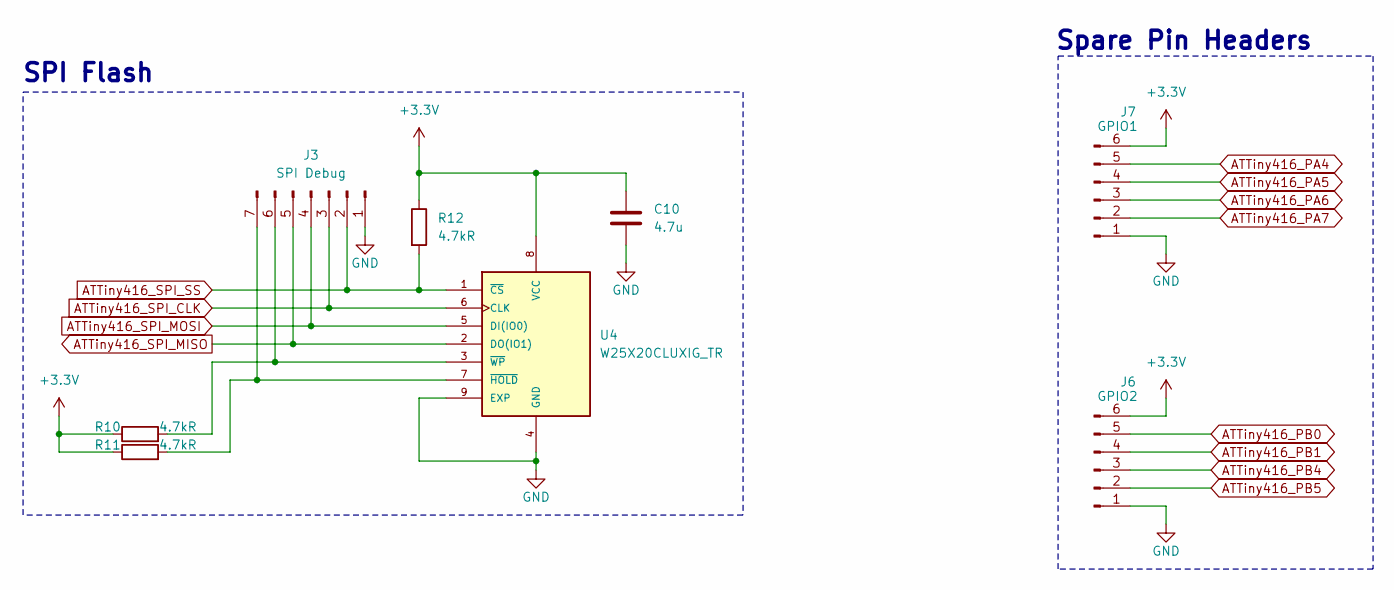
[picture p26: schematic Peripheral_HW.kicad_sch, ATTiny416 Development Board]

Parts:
C10: 4.7u; C_0805_2012Metric_Pad1.18x1.45mm_HandSolder
J3: SPI Debug; PinHeader_1x07_P2.54mm_Vertical
J6: GPIO2; PinHeader_1x06_P2.54mm_Vertical
J7: GPIO1; PinHeader_1x06_P2.54mm_Vertical
R10, R11, R12: 4.7kR; R_0805_2012Metric_Pad1.20x1.40mm_HandSolder
U4: W25X20CLUXIG_TR; W25X20CLUXIG TR

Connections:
+3.3V: C10.1, J6.6, J7.6, R10.1, R11.1, R12.1, U4.8 (VCC); also elsewhere on the board
ATTiny416_PA4: J7.5; also elsewhere on the board
ATTiny416_PA5: J7.4; also elsewhere on the board
ATTiny416_PA6: J7.3; also elsewhere on the board
ATTiny416_PA7: J7.2; also elsewhere on the board
ATTiny416_PB0: J6.5; also elsewhere on the board
ATTiny416_PB1: J6.4; also elsewhere on the board
ATTiny416_PB4: J6.3; also elsewhere on the board
ATTiny416_PB5: J6.2; also elsewhere on the board
ATTiny416_SPI_CLK: J3.3, U4.6 (CLK); also elsewhere on the board
ATTiny416_SPI_MISO: J3.5, U4.2 (DO(IO1)); also elsewhere on the board
ATTiny416_SPI_MOSI: J3.4, U4.5 (DI(IO0)); also elsewhere on the board
ATTiny416_SPI_SS: J3.2, R12.2, U4.1 (~CS); also elsewhere on the board
GND: C10.2, J3.1, J6.1, J7.1, U4.4 (GND), U4.9 (EXP); also elsewhere on the board
unnamed: J3.6, R10.2, U4.3 (~WP)
unnamed: J3.7, R11.2, U4.7 (~HOLD)

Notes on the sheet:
Spare Pin Headers
SPI Flash

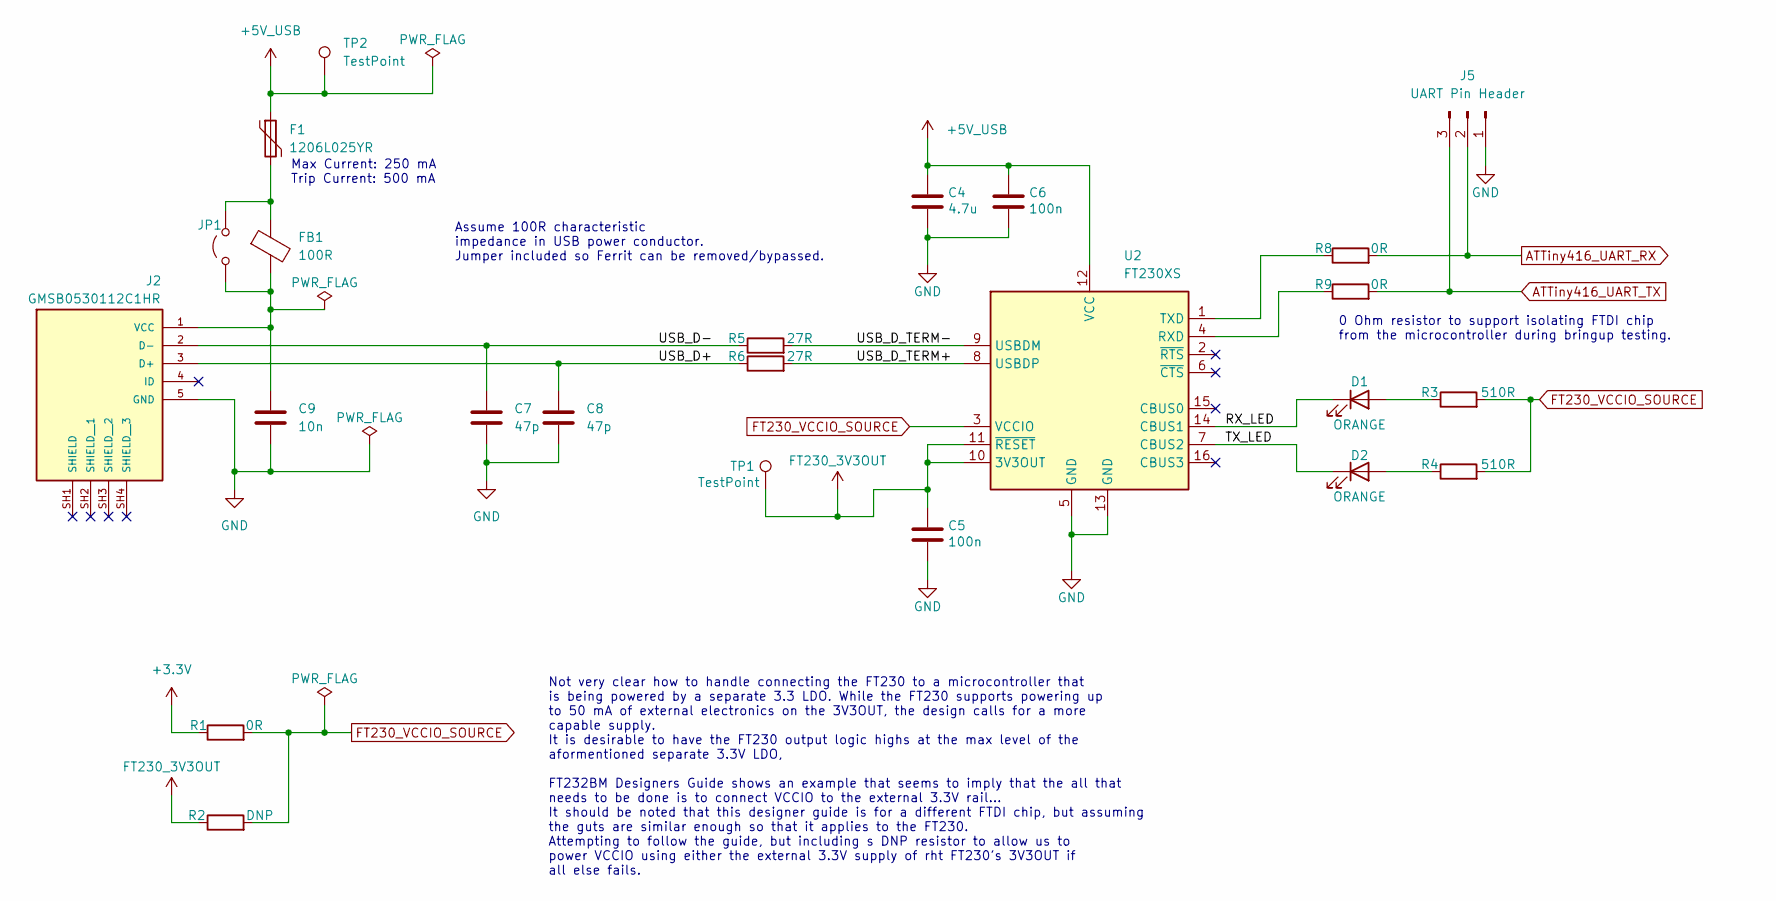
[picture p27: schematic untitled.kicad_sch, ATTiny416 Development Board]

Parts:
C4: 4.7u; C_0805_2012Metric_Pad1.18x1.45mm_HandSolder
C5, C6: 100n; C_0805_2012Metric_Pad1.18x1.45mm_HandSolder
C7, C8: 47p; C_0805_2012Metric_Pad1.18x1.45mm_HandSolder
C9: 10n; C_0805_2012Metric_Pad1.18x1.45mm_HandSolder
D1, D2: ORANGE; D_0805_2012Metric_Pad1.15x1.40mm_HandSolder
F1: 1206L025YR; Fuse_1206_3216Metric
FB1: 100R; R_1206_3216Metric_Pad1.30x1.75mm_HandSolder
J2: GMSB0530112C1HR; AMPHENOL_GMSB0530112C1HR; PARTREV AX4
J5: UART Pin Header; PinHeader_1x03_P2.54mm_Vertical
JP1: SolderJumper-2_P1.3mm_Open_RoundedPad1.0x1.5mm
R1, R8, R9: 0R; R_0805_2012Metric_Pad1.20x1.40mm_HandSolder
R2: DNP; R_0805_2012Metric_Pad1.20x1.40mm_HandSolder
R3, R4: 510R; R_0805_2012Metric_Pad1.20x1.40mm_HandSolder
R5, R6: 27R; R_0805_2012Metric_Pad1.20x1.40mm_HandSolder
TP1, TP2: TestPoint; TestPoint_Pad_D2.5mm
U2: FT230XS; SSOP-16_3.9x4.9mm_P0.635mm

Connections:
+3.3V: R1.1; also elsewhere on the board
+5V_USB: C4.1, C6.1, F1.1, TP2.1, U2.12 (VCC); also elsewhere on the board
/USB to UART Conversion/RX_LED: D1.1 (K), U2.14 (CBUS1)
/USB to UART Conversion/TX_LED: D2.1 (K), U2.7 (CBUS2)
/USB to UART Conversion/USB_D+: C8.1, J2.3 (D+), R6.1
/USB to UART Conversion/USB_D-: C7.1, J2.2 (D-), R5.1
/USB to UART Conversion/USB_D_TERM+: R6.2, U2.8 (USBDP)
/USB to UART Conversion/USB_D_TERM-: R5.2, U2.9 (USBDM)
ATTiny416_UART_RX: J5.2, R8.2; also elsewhere on the board
ATTiny416_UART_TX: J5.3, R9.2; also elsewhere on the board
FT230_3V3OUT: C5.1, R2.1, TP1.1, U2.10 (3V3OUT), U2.11 (~RESET)
FT230_VCCIO_SOURCE: R1.2, R2.2, R3.2, R4.2, U2.3 (VCCIO)
GND: C4.2, C5.2, C6.2, C7.2, C8.2, C9.2, J2.5 (GND), J5.1, U2.5 (GND), U2.13 (GND); also elsewhere on the board
unnamed: D1.2 (A), R3.1
unnamed: D2.2 (A), R4.1
unnamed: C9.1, FB1.2, J2.1 (VCC), JP1.1 (A)
unnamed: F1.2, FB1.1, JP1.2 (B)
unnamed: R9.1, U2.4 (RXD)
unnamed: R8.1, U2.1 (TXD)

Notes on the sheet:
Not very clear how to handle connecting the FT230 to a microcontroller that is being powered by a separate 3.3 LDO. While the FT230 supports powering up to 50 mA of external electronics on the 3V3OUT, the design calls for a more capable supply. It is desirable to have the FT230 output logic highs a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
0 Ohm resistor to support isolating FTDI chip from the microcontroller during bringup testing.
Assume 100R characteristic impedance in USB power conductor. Jumper included so Ferrit can be removed/bypassed.
Max Current: 250 mA Trip Current: 500 mA

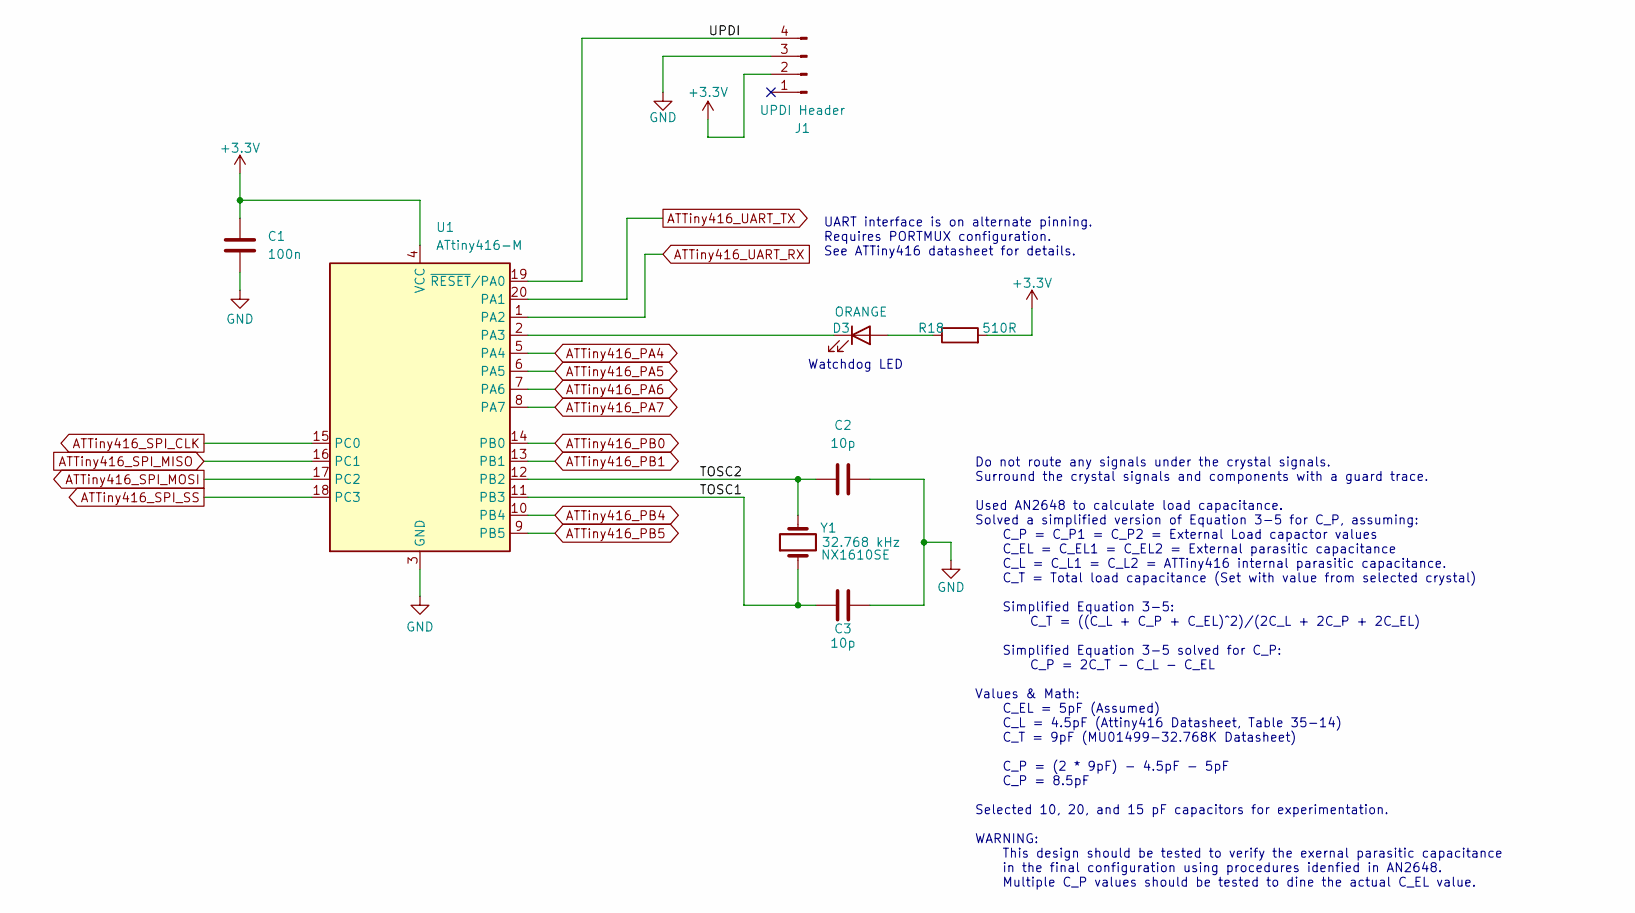
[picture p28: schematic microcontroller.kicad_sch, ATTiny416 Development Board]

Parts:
C1: 100n; C_0805_2012Metric_Pad1.18x1.45mm_HandSolder
C2, C3: 10p; C_0805_2012Metric_Pad1.18x1.45mm_HandSolder
D3: ORANGE; D_0805_2012Metric_Pad1.15x1.40mm_HandSolder
J1: UPDI Header; PinHeader_1x04_P2.54mm_Vertical
R18: 510R; R_0805_2012Metric_Pad1.20x1.40mm_HandSolder
U1: ATtiny416-M; VQFN-20-1EP_3x3mm_P0.4mm_EP1.7x1.7mm
Y1: 32.768 kHz; NX1610SE

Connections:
+3.3V: C1.1, J1.2, R18.2, U1.4 (VCC); also elsewhere on the board
/ATTiny416/TOSC1: C3.1, U1.11 (PB3), Y1.1
/ATTiny416/TOSC2: C2.1, U1.12 (PB2), Y1.2
/ATTiny416/UPDI: J1.4, U1.19 (~RESET/PA0)
ATTiny416_PA4: U1.5 (PA4); also elsewhere on the board
ATTiny416_PA5: U1.6 (PA5); also elsewhere on the board
ATTiny416_PA6: U1.7 (PA6); also elsewhere on the board
ATTiny416_PA7: U1.8 (PA7); also elsewhere on the board
ATTiny416_PB0: U1.14 (PB0); also elsewhere on the board
ATTiny416_PB1: U1.13 (PB1); also elsewhere on the board
ATTiny416_PB4: U1.10 (PB4); also elsewhere on the board
ATTiny416_PB5: U1.9 (PB5); also elsewhere on the board
ATTiny416_SPI_CLK: U1.15 (PC0); also elsewhere on the board
ATTiny416_SPI_MISO: U1.16 (PC1); also elsewhere on the board
ATTiny416_SPI_MOSI: U1.17 (PC2); also elsewhere on the board
ATTiny416_SPI_SS: U1.18 (PC3); also elsewhere on the board
ATTiny416_UART_RX: U1.1 (PA2); also elsewhere on the board
ATTiny416_UART_TX: U1.20 (PA1); also elsewhere on the board
GND: C1.2, C2.2, C3.2, J1.3, U1.3 (GND), U1.21 (GND); also elsewhere on the board
unnamed: D3.2 (A), R18.1
unnamed: D3.1 (K), U1.2 (PA3)

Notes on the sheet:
Do not route any signals under the crystal signals. Surround the crystal signals and components with a guard trace. Used AN2648 to calculate load capacitance. Solved a simplified version of Equation 3-5 for C_P, assuming: C_P = C_P1 = C_P2 = External Load capactor values C_EL = C_EL1 = C_EL2 = Exte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
UART interface is on alternate pinning. Requires PORTMUX configuration. See ATTiny416 datasheet for details.
Watchdog LED

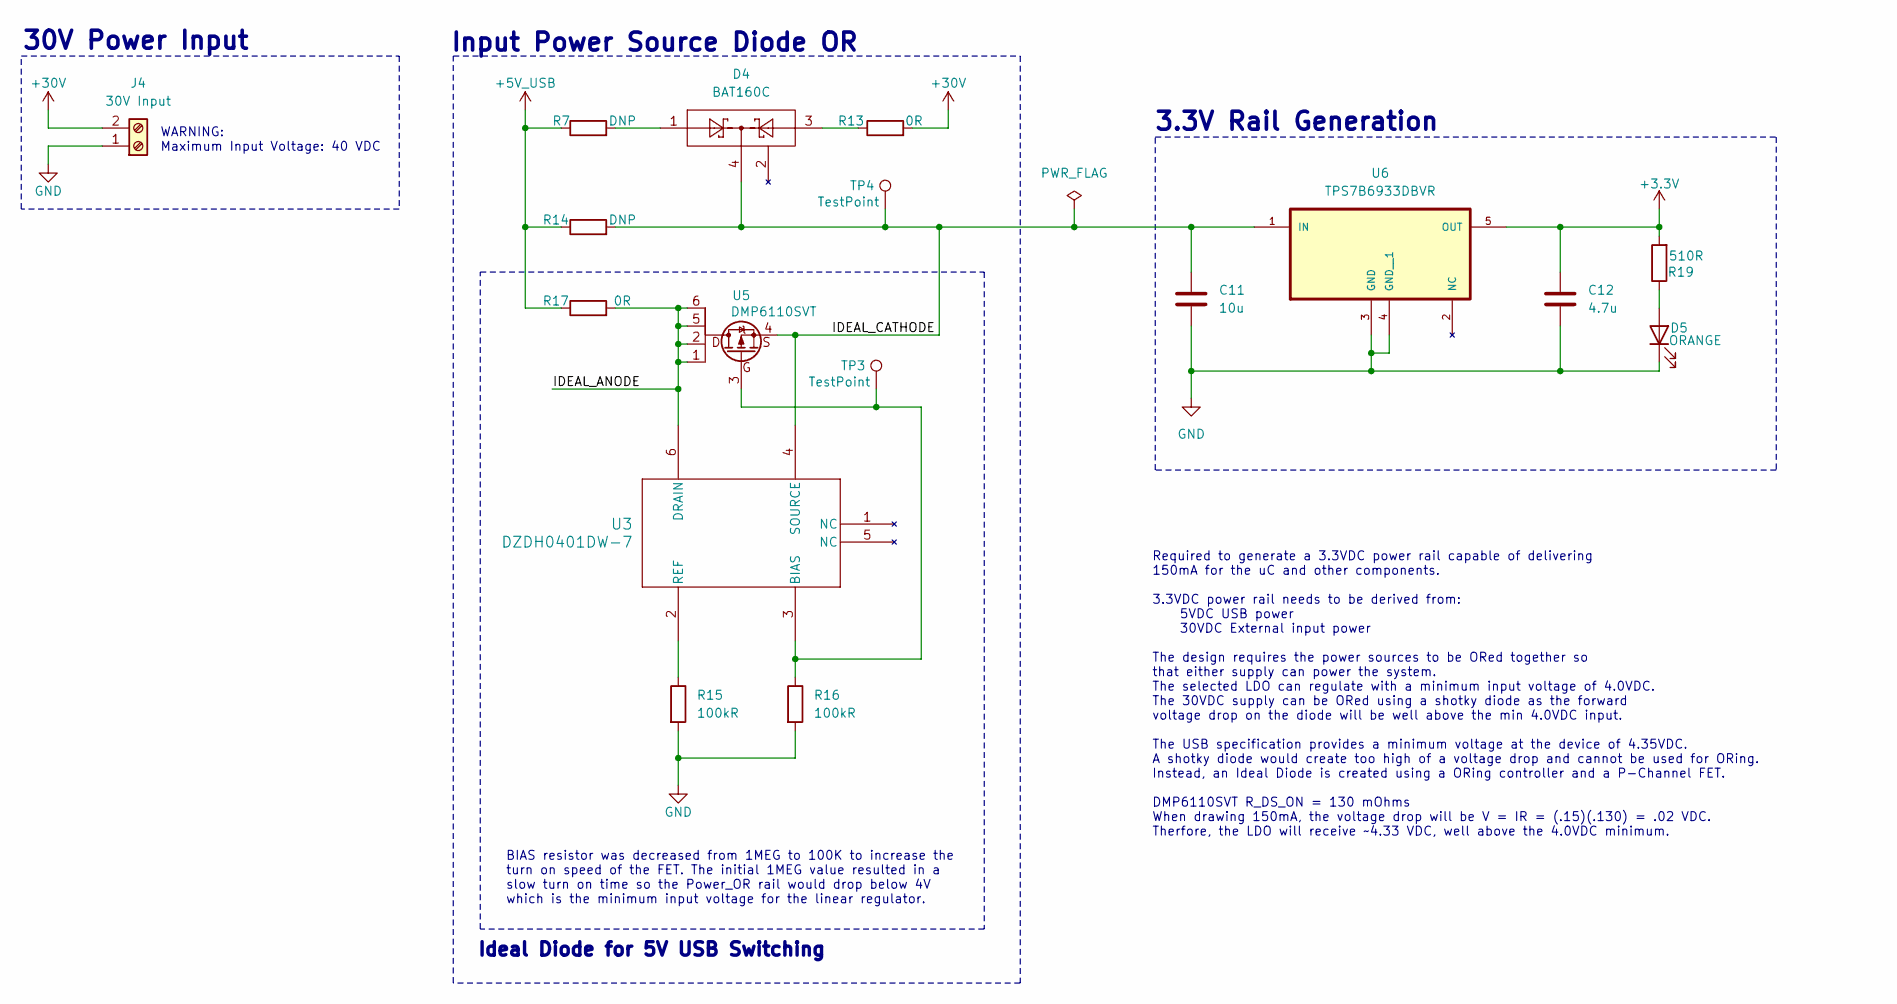
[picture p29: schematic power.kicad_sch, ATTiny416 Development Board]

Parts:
C11: 10u; C_1210_3225Metric_Pad1.33x2.70mm_HandSolder
C12: 4.7u; C_0805_2012Metric_Pad1.18x1.45mm_HandSolder
D4: BAT160C; SOT-223
D5: ORANGE; D_0805_2012Metric_Pad1.15x1.40mm_HandSolder
J4: 30V Input; Two_Position_Screw_Terminal
R7, R14: DNP; R_0805_2012Metric_Pad1.20x1.40mm_HandSolder
R13, R17: 0R; R_0805_2012Metric_Pad1.20x1.40mm_HandSolder
R15, R16: 100kR; R_0805_2012Metric_Pad1.20x1.40mm_HandSolder
R19: 510R; R_0805_2012Metric_Pad1.20x1.40mm_HandSolder
TP3, TP4: TestPoint; TestPoint_Pad_D2.5mm
U3: DZDH0401DW-7; SOT-363_SC-70-6_Handsoldering
U5: DMP6110SVT
U6: TPS7B6933DBVR; SOT-23-5

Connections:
+3.3V: C12.2, R19.2, U6.5 (OUT); also elsewhere on the board
+5V_USB: R7.1, R14.1, R17.1; also elsewhere on the board
+30V: J4.2, R13.2
/Power/IDEAL_ANODE: R17.2, U3.6 (DRAIN), U5.1, U5.2, U5.5, U5.6
/Power/IDEAL_CATHODE: C11.2, D4.4, R14.2, TP4.1, U3.4 (SOURCE), U5.4, U6.1 (IN)
GND: C11.1, C12.1, D5.1 (K), J4.1, R15.2, R16.2, U6.3 (GND), U6.4 (GND__1); also elsewhere on the board
unnamed: D4.1, R7.2
unnamed: D4.3, R13.1
unnamed: D5.2 (A), R19.1
unnamed: R16.1, TP3.1, U3.3 (BIAS), U5.3
unnamed: R15.1, U3.2 (REF)

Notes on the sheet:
Input Power Source Diode OR
WARNING: Maximum Input Voltage: 40 VDC
30V Power Input
Ideal Diode for 5V USB Switching
Required to generate a 3.3VDC power rail capable of delivering 150mA for the uC and other components. 3.3VDC power rail needs to be derived from: 5VDC USB power 30VDC External input power The design requires the power sources to be ORed together so that either supply can power the system. The selec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
BIAS resistor was decreased from 1MEG to 100K to increase the turn on speed of the FET. The initial 1MEG value resulted in a slow turn on time so the Power_OR rail would drop below 4V which is the minimum input voltage for the linear regulator.
3.3V Rail Generation

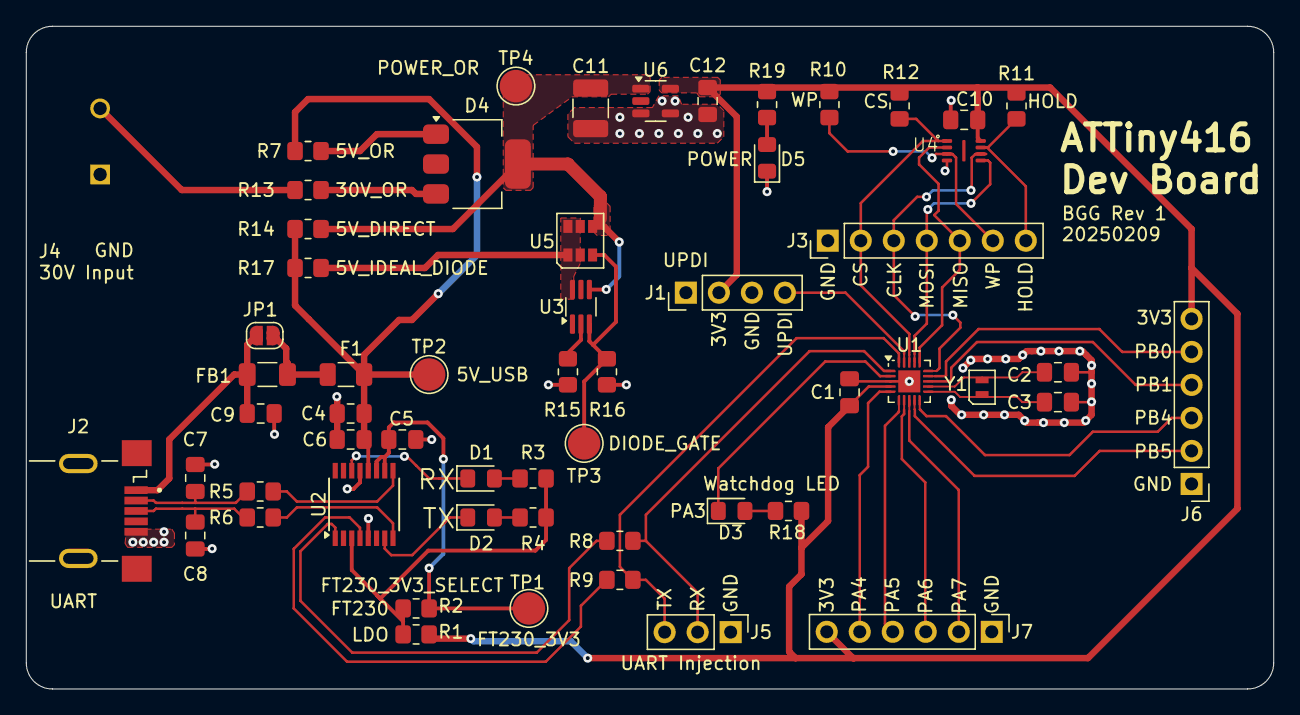
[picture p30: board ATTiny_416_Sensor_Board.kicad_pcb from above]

Board: 2 copper layers, 96.0 x 51.0 mm, 57 parts (0 on the bottom side), 46 nets.

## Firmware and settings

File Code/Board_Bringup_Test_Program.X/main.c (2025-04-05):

/*
 * File:   main.c
 * Author: byrongaspard
 *
 * Created on February 15, 2025, 3:23 PM
 * 
 * This test program exercises the interfacing hardware on the custom ATTiny416 
 * development board. 
 * It initializes an external serial communication interface to the FTDI230 chip.
 * Additionally, it exercises the external W25X20L flash chip.
 * 
 * Connecting PA6 to ground will cause the ATTiny416 to dump the contents of
 * the W25X20L flash to the UART interface. 
 * Connecting PA7 to ground will cause the ATTiny416 to erase the W25X20L flash.
 * If both PA6 and PA7 are left floating, the ATTiny416 will look for the beginning
 * of uninitialized flash and begin recording data.
 * 
 * TODO: Separate code out into logical *.c and *.h files. 
 * 
 */

// Clock Speed, including the Peripheral Clock.
// Trap for new players: F_CPU must be defined before including the delay.h library for the delay calls to work.
#define F_CPU   3300000UL
                
#include <stdio.h>
#include <stdlib.h>
#include <avr/io.h>
#include <util/delay.h>
#include <avr/xmega.h>

#define TRUE                (1)
#define FALSE               (0)

// General Bit Getting/Setting/Clearing utilities
#define GET_BIT(p,n) ((p >> n) & 0x1)
#define SET_BIT(p,n) ((p) |= (0x1 << (n)))
#define CLR_BIT(p,n) ((p) &= ~((0x1) << (n)))

// USART Definitions
#define USART_S             (16UL)      
#define USART_REG_FRACT     (64UL)    
#define BAUD_RATE           (115200UL)
#define BAUD_REG_VAL        ( ((float)USART_REG_FRACT * F_CPU)/((float)USART_S * BAUD_RATE) )

// W25X20L Info
#define W25X20L_MFR_ID              (0xEF)
#define W25X20L_DEV_ID              (0x11)
#define W25X20L_START_ADDR          (0x000000)
#define W25X20L_END_ADDR            (0x03FFFF)
#define W25X20L_PAGE_BYTES          (256)
#define W25X20L_STATUS_REG_WEN_BIT  (1UL)
#define W25X20L_STATUS_REG_BUSY_BIT (0UL)
#define W25X20L_NUM_PAGES           ((W25X20L_END_ADDR + 1UL) / W25X20L_PAGE_BYTES)
#define W25X20L_CHIP_ERASE_TIME_MS  (2500UL)

// W25X20L SPI Flash Commands
#define W25X20L_READ_MFR_DEV_ID     (0x90)
#define W25X20L_WRITE_ENABLE        (0x06)
#define W25X20L_READ_STATUS_REG     (0x05)
#define W25X20L_CHIP_ERASE          (0xC7)
#define W25X20L_READ_DATA           (0x03) 
#define W25X20L_PAGE_PROGRAM        (0x02)

// SPI helper commands
#define ASSERT_SELECT       (0)
#define DEASSERT_SELECT     (1)

// Global Variables
volatile uint32_t cur_spi_write_addr = 0UL;
volatile uint8_t spi_write_permitted = FALSE;

// Function prototypes
void initialize_clock(void);
void configure_alt_pinning(void);
void configure_data_direction(void);
void configure_uart(void);
void configure_spi(void);
void set_spi_cs(uint8_t val);
uint8_t spi_transfer(uint8_t byte);
void get_spi_device_id(void);

void W25X20L_write_enable(void);
void W25X20L_chip_erase(void);
void W25X20L_find_uninitialized_memory(void);
void W25X20L_write_data(uint8_t *data, uint8_t num_bytes);
void W25X20L_dump_flash_to_uart(void);
uint8_t W25X20L_get_status_reg(void);

void send_uart_byte(uint8_t byte);
void send_uart_string(char* str);
void send_uart_ascii_hex_byte(uint8_t byte);

void main(void) 
{
    // Test recording array
    uint8_t test_arr[] = {1, 2, 3, 99};
    
    // Initialize everything
    initialize_clock();
    configure_alt_pinning();
    configure_data_direction();
    configure_uart();
    configure_spi();

    // Check that the W25X20L is detected
    get_spi_device_id();

   
    if(!GET_BIT(PORTA.IN, 6))
    {
        send_uart_string("PA6 is LOW. Dumping Flash\n");
        W25X20L_dump_flash_to_uart();
        send_uart_string("\n\nFlash dump complete! Reboot required.\n");
        while(1);
    }
    
    if(!GET_BIT(PORTA.IN, 7))
    {
        send_uart_string("PA7 is LOW. Erasing Flash. \n");
        W25X20L_chip_erase();
        send_uart_string("Reboot required. \n");
        while(1);
    }
    
    W25X20L_find_uninitialized_memory();
    
    while(1)
    {
        if(GET_BIT(PORTA.IN, 6))
        {
            W25X20L_write_enable();
            //send_uart_string("PA6 is HIGH. Recording Data. \n");
            W25X20L_write_data(test_arr, sizeof(test_arr)/sizeof(test_arr[0]));
            test_arr[0]++;
        }
        
        //_delay_ms(1000);
    }
    return;
}

void initialize_clock(void)
{
    // NOP...
    return;
}


void configure_alt_pinning(void)
{
    SET_BIT(PORTMUX.CTRLB, 0); // Configure USART0 to use alternate pinning.
    SET_BIT(PORTMUX.CTRLB, 2); // Configure SPI0 to use alternate pinning.
    return;
}

void configure_data_direction(void)
{
    // USART Configuration
        SET_BIT(PORTA.OUT, 1);  // TxD is on PA1. Initialize HIGH (idle).
        SET_BIT(PORTA.DIR, 1);  // TxD is on PA1. Initialize as output.
        CLR_BIT(PORTA.DIR, 2);  // RxD is on PA2. Initialize as input.

    // SPI Configuration
        CLR_BIT(PORTC.OUT, 0);  // CLK is on PC0. Initialize low.
        SET_BIT(PORTC.DIR, 0);  // CLK is on PC0. Initialize as output.

        CLR_BIT(PORTC.DIR, 1);  // MISO is on PC1. Initialize as input.

        CLR_BIT(PORTC.OUT, 2);  // MOSI is on PC2. Initialize low. 
        SET_BIT(PORTC.DIR, 2);  // MOSI is on PC2. Initialize as output. 

        SET_BIT(PORTC.OUT, 3);  // CS/SS is on PC3. Initialize high.
        SET_BIT(PORTC.DIR, 3);  // CS/SS is on PC3. Configure as output. 
    
    // LED Configuration
        CLR_BIT(PORTA.OUT, 3); // LED is on PA3. Initialize ON.
        SET_BIT(PORTA.DIR, 3); // LED is on PA3. Configure as output.
        
    // GPIO Configuration
        CLR_BIT(PORTA.DIR, 7);      // GPIO input on PA7
        SET_BIT(PORTA.PIN7CTRL, 3); // Enable pull-up resistor
       
        CLR_BIT(PORTA.DIR, 6);      // GPIO input on PA6
        SET_BIT(PORTA.PIN6CTRL, 3); // Enable pull-up resistor

    return;
}

void configure_uart(void)
{    
    // Set the baud rate (in the USARTn.BAUD register) and frame format.
    USART0.BAUD = (uint16_t)BAUD_REG_VAL;
   
    // Enable the transmitter and the receiver.
    SET_BIT(USART0.CTRLB, 7); // Enable the receiver
    SET_BIT(USART0.CTRLB, 6); // Enable the transmitter
    
    // Wait until the transmitter is ready by checking DREIF
    while(!GET_BIT(USART0.STATUS, 5)); 
    
    send_uart_string("\n\nBooting...\n");
    send_uart_string("UART Initialized.\n");
    
    return;
}

void configure_spi(void)
{
    CLR_BIT(SPI0.CTRLA, 6); // MSb is sent first.
    SET_BIT(SPI0.CTRLA, 5); // Configure as Host/Master
    SET_BIT(SPI0.CTRLA, 4); // Double clock speed
    SET_BIT(SPI0.CTRLA, 0); // Enable SPI Interface
    
    send_uart_string("SPI Initialized.\n");
    
    return;
}

void set_spi_cs(uint8_t val)
{
    if(val == ASSERT_SELECT)
    {
        CLR_BIT(PORTC.OUT, 3);  // CS/SS is on PC3. Set LOW to select chip.
    }
    else
    {
        SET_BIT(PORTC.OUT, 3);  // CS/SS is on PC3. Set LOW to select chip.
    }
}

uint8_t spi_transfer(uint8_t byte)
{
    SPI0.DATA = byte; // Send the data
    while(!(SPI0.INTFLAGS & SPI_IF_bm)); // Loop until the transmit is complete
    return SPI0.DATA;
}

void get_spi_device_id(void)
{
    uint8_t mfr_id = 0x00;
    uint8_t dev_id = 0x00;
    
    //TODO: Replace this with the JEDEC ID call.
    
    // Wait until the chip is ready.
    while(GET_BIT(W25X20L_get_status_reg(), W25X20L_STATUS_REG_BUSY_BIT)) _delay_us(1);
    
    set_spi_cs(ASSERT_SELECT);
    
    /* Send the command IAW W25X20L datasheet. */
    spi_transfer(W25X20L_READ_MFR_DEV_ID);
    spi_transfer(0x00);
    spi_transfer(0x00);
    spi_transfer(0x00);
    
    mfr_id = spi_transfer(0x00);
    dev_id = spi_transfer(0x00);
    
    set_spi_cs(DEASSERT_SELECT);
    
    // Verify the mfr and dev IDs are what is expected.
    if(mfr_id != W25X20L_MFR_ID || dev_id != W25X20L_DEV_ID)
    {
        send_uart_string("WARNING: detected illegal flash chip");
        send_uart_string("mfr_id is 0x");
        send_uart_ascii_hex_byte(mfr_id);
        send_uart_string("\n");

        send_uart_string("device_id is 0x");
        send_uart_ascii_hex_byte(dev_id);
        send_uart_string("\n");
        // TODO: Add error handling here so we don't try to write if we're not 
        // talking to the right chip.
    }
    else
    {
        send_uart_string("Detected W25X20L Flash Chip.\n");
    }
}

uint8_t W25X20L_get_status_reg(void)
{
    uint8_t status_reg = 0x00;
    
    // Read the status register.
    set_spi_cs(ASSERT_SELECT);
    spi_transfer(W25X20L_READ_STATUS_REG);
    status_reg = spi_transfer(0x00);
    set_spi_cs(DEASSERT_SELECT);
    
    return status_reg;
}

void W25X20L_write_enable(void)
{
    // Wait until the chip is ready.
    while(GET_BIT(W25X20L_get_status_reg(), W25X20L_STATUS_REG_BUSY_BIT)) _delay_us(1);
    
    // Send Write Enable command.
    set_spi_cs(ASSERT_SELECT);
    spi_transfer(W25X20L_WRITE_ENABLE);
    set_spi_cs(DEASSERT_SELECT);
    
    if(!GET_BIT(W25X20L_get_status_reg(), W25X20L_STATUS_REG_WEN_BIT))
    {
        send_uart_string("ERROR: Write enable failed.\n");
        spi_write_permitted = FALSE;
    }
    
    return;
}

void W25X20L_chip_erase(void)
{
    // Enable writes.
    W25X20L_write_enable();
    
    // Wait until the chip is ready.
    while(GET_BIT(W25X20L_get_status_reg(), W25X20L_STATUS_REG_BUSY_BIT)) _delay_us(1);
    
    // Send the erase command.
    set_spi_cs(ASSERT_SELECT);
    spi_transfer(W25X20L_CHIP_ERASE);
    set_spi_cs(DEASSERT_SELECT);

    // Poll the status register until the erase is complete as indicated by the BUSY bit.
     while(GET_BIT(W25X20L_get_status_reg(), W25X20L_STATUS_REG_BUSY_BIT))
     {
         _delay_ms(100);
        send_uart_string("Erasing...\n");
     }
    
    send_uart_string("W25X20L Erase Complete.\n");
}

/*
 * This through iterates through flash until it finds 16 consecutive bytes of 0xFF.
 * The memory address is then aligned to the nearest 16-byte boundary which is considered
 * to be the start of uninitialized memory.
 */
void W25X20L_find_uninitialized_memory(void)
{
    uint8_t consec_uninit_bytes = 0;
    uint32_t cur_addr = W25X20L_START_ADDR;
    uint32_t start_addr = W25X20L_START_ADDR;
    
    // Wait until the chip is ready.
    while(GET_BIT(W25X20L_get_status_reg(), W25X20L_STATUS_REG_BUSY_BIT)) _delay_us(1);
    
    // Send the Read Data command IAW W25X20L datasheet
    // Start reading from the beginning of memory
    set_spi_cs(ASSERT_SELECT);
    spi_transfer(W25X20L_READ_DATA); // Send the read command.
    spi_transfer((cur_addr >> 16) & 0xFF);  // Shift upper byte of address
    spi_transfer((cur_addr >> 8) & 0xFF);   // Shift middle byte of address
    spi_transfer((cur_addr >> 0) & 0xFF);   // Shift lower byte of address
    
    // Loop while there is still data to read
    while(cur_addr <= W25X20L_END_ADDR)
    {
        if(spi_transfer(0x00) == 0xFF)
        {
            consec_uninit_bytes++;
            
            // If the start of uninitialized flash has been found, find the nearest
            // 16-byte aligned address.
            if(consec_uninit_bytes == 16)
            {
                start_addr = cur_addr & 0xFFFFFFF0;
                
                send_uart_string("Start of memory is at 0x");
                send_uart_ascii_hex_byte(((start_addr) >> 16) & 0xFF);
                send_uart_ascii_hex_byte(((start_addr) >> 8) & 0xFF);
                send_uart_ascii_hex_byte(((start_addr) >> 0) & 0xFF);
                send_uart_string("\n");
                
                cur_spi_write_addr = start_addr;
                spi_write_permitted = TRUE;
                
                return;
            }
        }
        else
        {
            consec_uninit_bytes = 0;
        }
        cur_addr ++;
    }
    
    send_uart_string("Could not find start of memory.");
    set_spi_cs(DEASSERT_SELECT);
}

void W25X20L_write_data(uint8_t *data, uint8_t num_bytes)
{    
    // Check that there is enough memory to write the data.
    if((cur_spi_write_addr + num_bytes) > W25X20L_END_ADDR + 1)
    {
        send_uart_string("Aborting W25X20L write... not enough memory left\n");
        while(1);
        return;
    }
    // CHeck that the write does not cross page boundaries.
    if(((cur_spi_write_addr % W25X20L_PAGE_BYTES) + num_bytes) > W25X20L_PAGE_BYTES)
    {
        // Feature: Make this function recursive to support multi-page writes.
        send_uart_string("Aborting W25X20L write... the requested write crosses page boundaries. Not supported.\n");
        return;
    }
    
    /* Enable writes */
    W25X20L_write_enable();
    
    if(spi_write_permitted == TRUE)
    {
        /* Wait until the chip is ready */
        while(GET_BIT(W25X20L_get_status_reg(), W25X20L_STATUS_REG_BUSY_BIT)) _delay_us(1);

        set_spi_cs(ASSERT_SELECT);
        spi_transfer(W25X20L_PAGE_PROGRAM); // Send the program command.
        spi_transfer((cur_spi_write_addr >> 16) & 0xFF);  // Shift upper byte of address
        spi_transfer((cur_spi_write_addr >> 8) & 0xFF);   // Shift middle byte of address
        spi_transfer((cur_spi_write_addr >> 0) & 0xFF);   // Shift lower byte of address
        for(uint8_t i = 0; i < num_bytes; i++)
        {
            spi_transfer(data[i]);
        }
        set_spi_cs(DEASSERT_SELECT);

        _delay_ms(10);

        cur_spi_write_addr += num_bytes;
    }
    return;
}

void W25X20L_dump_flash_to_uart(void)
{
    uint32_t cur_addr = W25X20L_START_ADDR;
    uint8_t cur_byte = 0x00;
    uint8_t checksum = 0x00;
    
    /* Wait until the chip is ready */
    while(GET_BIT(W25X20L_get_status_reg(), W25X20L_STATUS_REG_BUSY_BIT)) _delay_us(1);
  
    // Dump one page at a time
    for(uint32_t cur_page = 0; cur_page < W25X20L_NUM_PAGES; cur_page++)
    {
        cur_addr = W25X20L_START_ADDR + (cur_page * W25X20L_PAGE_BYTES);
        
        set_spi_cs(ASSERT_SELECT);
        spi_transfer(W25X20L_READ_DATA); // Send the read command.
        spi_transfer((cur_addr >> 16) & 0xFF);  // Shift upper byte of address
        spi_transfer((cur_addr >> 8) & 0xFF);   // Shift middle byte of address
        spi_transfer((cur_addr >> 0) & 0xFF);   // Shift lower byte of address
        
        for(uint32_t cur_page_byte = 0; cur_page_byte < W25X20L_PAGE_BYTES; cur_page_byte ++)
        {
            if (((cur_page_byte) % 16) == 0 && cur_page_byte < W25X20L_PAGE_BYTES)
            {
                send_uart_string("\n");
                send_uart_string("0x");
                send_uart_ascii_hex_byte(((cur_addr + cur_page_byte) >> 16) & 0xFF);
                send_uart_ascii_hex_byte(((cur_addr + cur_page_byte) >> 8) & 0xFF);
                send_uart_ascii_hex_byte(((cur_addr + cur_page_byte) >> 0) & 0xFF);
                send_uart_string(": ");
            }
            cur_byte = spi_transfer(0x00);
            checksum += cur_byte;
            send_uart_ascii_hex_byte(cur_byte);
        }
        
        set_spi_cs(DEASSERT_SELECT);
    }
    
    send_uart_string("\n\n8-Bit Two's Compliment Checksum: 0x");
    send_uart_ascii_hex_byte(~checksum + 1);
    send_uart_string("\n");
}

/***** USART Helper Functions ******/

void send_uart_byte(uint8_t byte)
{
    // Wait until the transmitter is ready by checking DREIF
    while(!GET_BIT(USART0.STATUS, 5));    
    
    // Send the data
    USART0.TXDATAL = byte;
    
    return;
}

// WARNING: This function requires the caller to provide a null-terminated string.
void send_uart_string(char* str)
{
    uint32_t i = 0;
    while(str[i] != '\0')
    {
        send_uart_byte((uint8_t) str[i]);
        i++;
    }
    
    return;
}

void send_uart_ascii_hex_byte(uint8_t byte)
{
    uint8_t cur_nibble;
    
    cur_nibble = ((byte >> 4) & 0xF);
    
    if(cur_nibble < 0xA) cur_nibble += 48;
    else cur_nibble += 55;
    
    send_uart_byte(cur_nibble);
    
    cur_nibble = ((byte) & 0xF);
    
    if(cur_nibble < 0xA) cur_nibble += 48;
    else cur_nibble += 55;
    
    send_uart_byte(cur_nibble);
                        
    return;
}

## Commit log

2025-02-15 Initial release for mfr
    [2171790001.stp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]
2025-02-16 including first schematic revision plot
2025-02-16 Initial code for board bringup
2025-02-16 cleaning up kicad docs
    [ATTiny_416_Sensor_Board.kicad_pcb, ATTiny_416_Sensor_Board.kicad_sch, Peripheral_HW.kicad_sch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]
2025-02-16 Cleaned up Schematics
    [ATTiny_416_Sensor_Board.kicad_pcb, ATTiny_416_Sensor_Board.kicad_sch, Peripheral_HW.kicad_sch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]
2025-02-17 Bringup code updated to exercise SPI and UART interaces
2025-02-17 Fixed code that was incorrectly checking for the end of flash and allowing end of flash to go unused. Added two's compliment checksum when dumping flash
    [main.c]
2025-04-05 Fixed no-erase bug by ensuring SPI chip has writes enabled before sending erase command
    [main.c]
2025-04-05 removed bad schematic notes and re-plotted
    [ATTiny_416_Sensor_Board.kicad_sch, Peripheral_HW.kicad_sch, microcontroller.kicad_sch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]
2025-04-05 updated USB input voltage to the correct minimum (4.35).
